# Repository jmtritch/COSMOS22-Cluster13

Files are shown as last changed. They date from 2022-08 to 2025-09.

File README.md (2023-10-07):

# UCSD COSMOS 2022 Cluster13 - H4O: Hacking for Oceans

This Cluster was inspired by the success of the [Scripps Institute of Oceanography and UCSD’s Hacking for the Oceans](http://h4oceans.ucsd.edu/) graduate and undergraduate level class.

During this inaugural year students applied engineering theory and industry-recognized best practices in the development of affordable instrumentation and robotic devices by innovating and adopting new technologies to monitor, generate and analyze data for our oceans at scale. Students worked in teams to:

* Develop a surface unmanned autonomous vehicle (UAV) including testing and documentation.
* Select and integrate low power and affordable instrumentation for the UAV using microcontrollers.
* Collect, visualize, model, and analyize water quality data, including temperature, total dissovled solids, and pH levels.

Students explored and applied principles of autonomous robots, microcontrollers, Python, and data visualization and analysis tools.

Working in 5 teams, students had to achieve their team objectives while ensuring that their work integrated seemlessly with the work of the other teams.  This required teams to identify goals, project timelines, and protocols for communication between devices and team inputs and outputs.

## Video Overview

COSMOS 2022 Cluster 13 (https://www.youtube.com/watch?v=VEP8hvSK_jM)

## Teams

1. Boat
   * Worked on converting a Traxxas high-speed RC Boat into an autonomous boat: integrated a flight controller, GPS, and a radio for communicating with an autopilot software on a base station computer, designed and printed enclosures for protecting the electronics from water damage, and modified the steering system to be more agile.
2. Buoy
   * Designed and constructed the buoy-based instrumentation for data collection. Two buoys were constructed.  The first buoy was designed to collect sea-surface data with the instrumentation submerged off the sides.  The second buoy was designed to lower and raise sumbersible instrumentation to collect vertical profiles of water quality data.
3. Data Acquisition
   * Ensured accurate data readings by calibrating and oversampling the sensor data.  Programmed the microcontroller to send the sensor data to the telemetry microcontroller.  Multiple microcontrollers were necessary becasuse the instrumentation in the second buoy was packeged in a submersible payload. Worked collaboratively with the telemetry team to develop the communication protocol (serial) and data format for communication.
4. Telemetry
   * Responsible for data communication between buoys and base station.  Programmed a buoy-based microcontroller to receive sensor data via Serial connection, combine the data with a timestamp and GPS coordinates, and transmit that data via long range radio (LoRa) to the base-station.  The base-station LoRa microcontroller recieves the data and transmits it to a linux-based server via Serial connection.
5. Data Storage and Analysis
   * Configured the server to receive the sensor data from the telemetry team's base-station microcontroller via serial connection.  Designed a normalized database in SQLite to store the data.  Developed a python script to receive the data via serial connection and populate the database.  Developed a Python-based databoard to visualize the data as it is received.  Utilized Python and Jupyter notebooks to visualize, model, and analyze the data.

## Data Flow

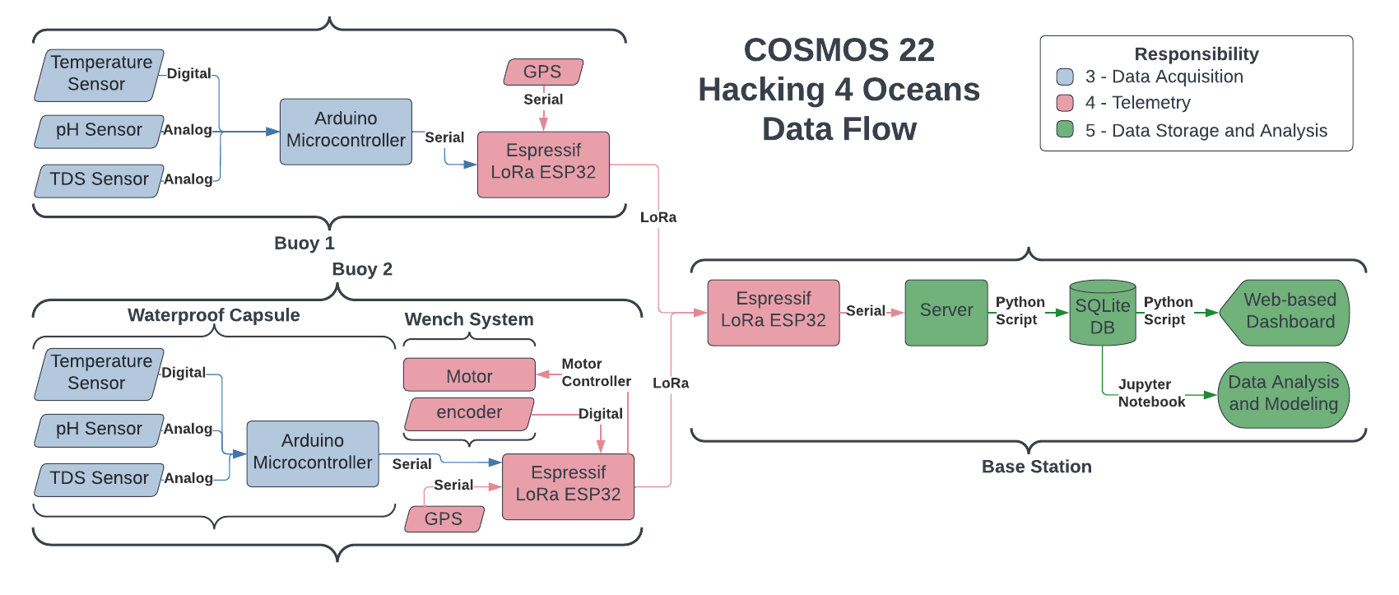
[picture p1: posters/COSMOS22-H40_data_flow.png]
Data Flow


## Team Posters

### 1 - Boat
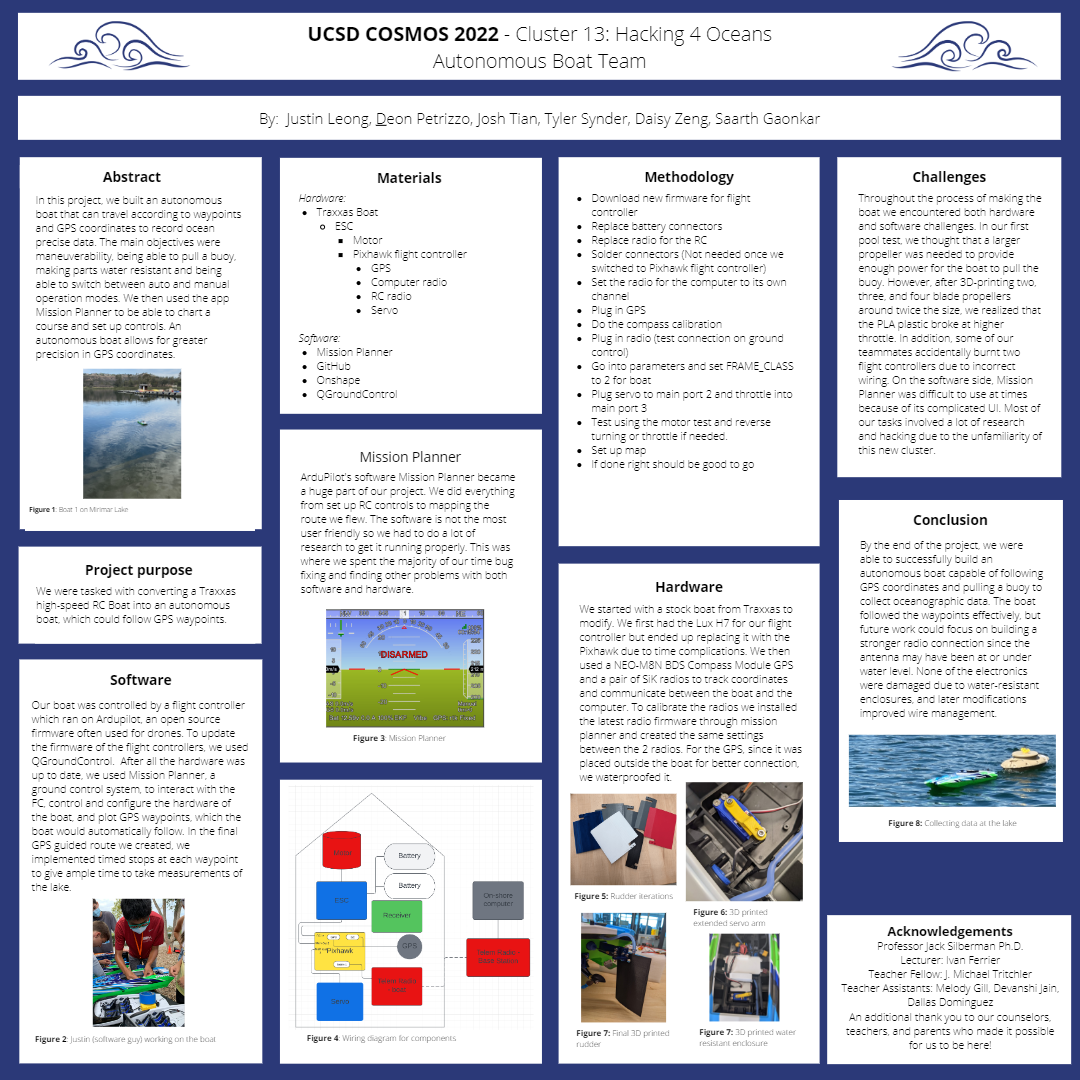
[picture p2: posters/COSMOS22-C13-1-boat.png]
Team 1 - Boat

### 2 - Buoy
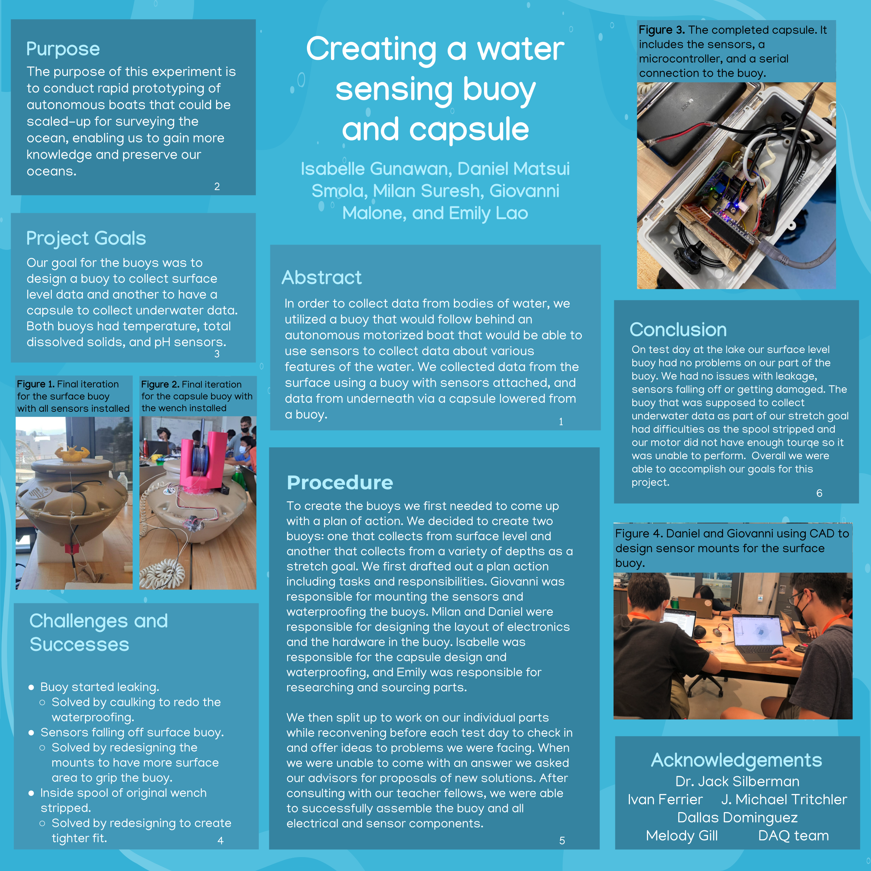
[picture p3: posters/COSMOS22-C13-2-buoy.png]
Team 2 - Buoy

### 3 - Data Acquisition
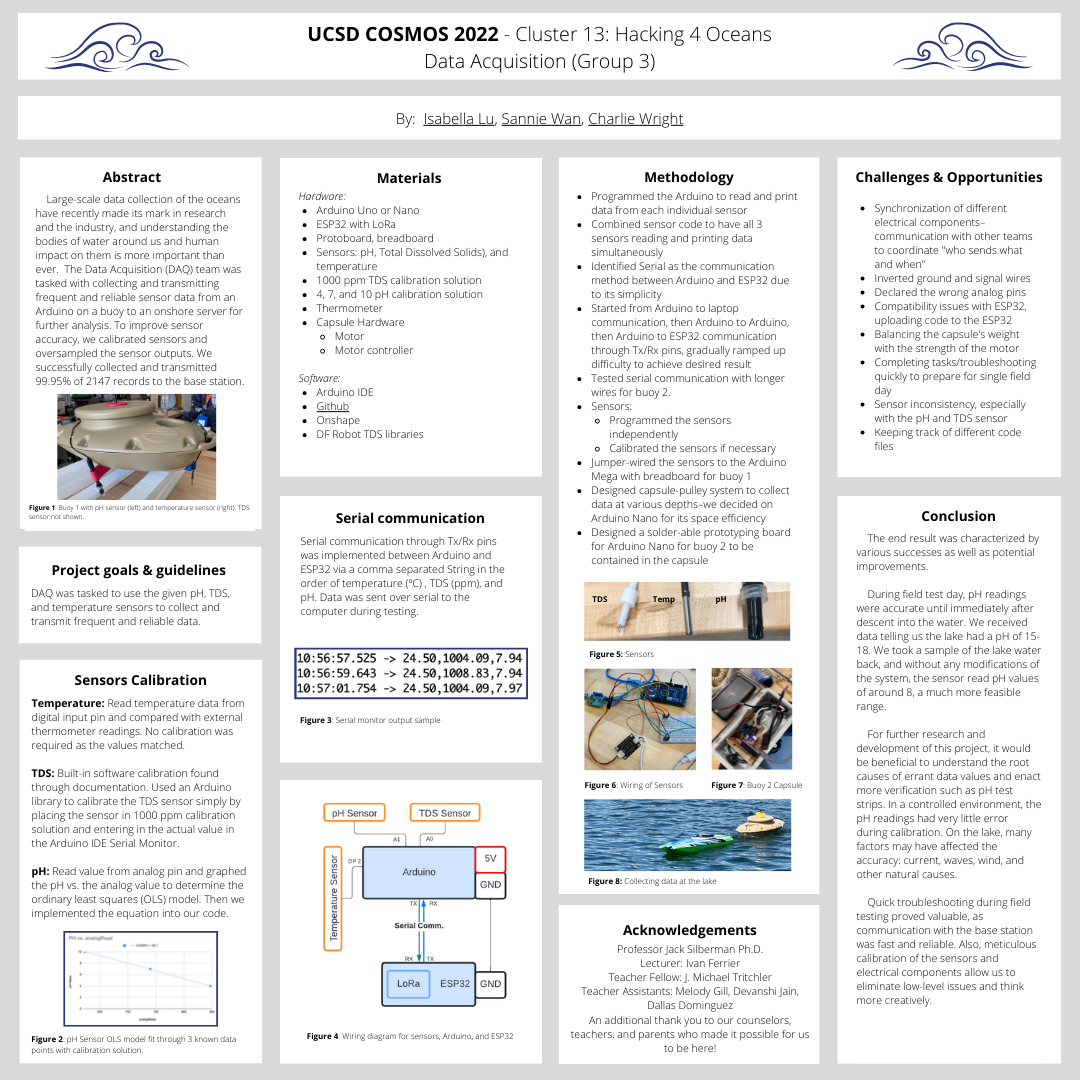
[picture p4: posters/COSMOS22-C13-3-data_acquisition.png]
Team 3 - Data Acquisition

### 4 - Telemetry
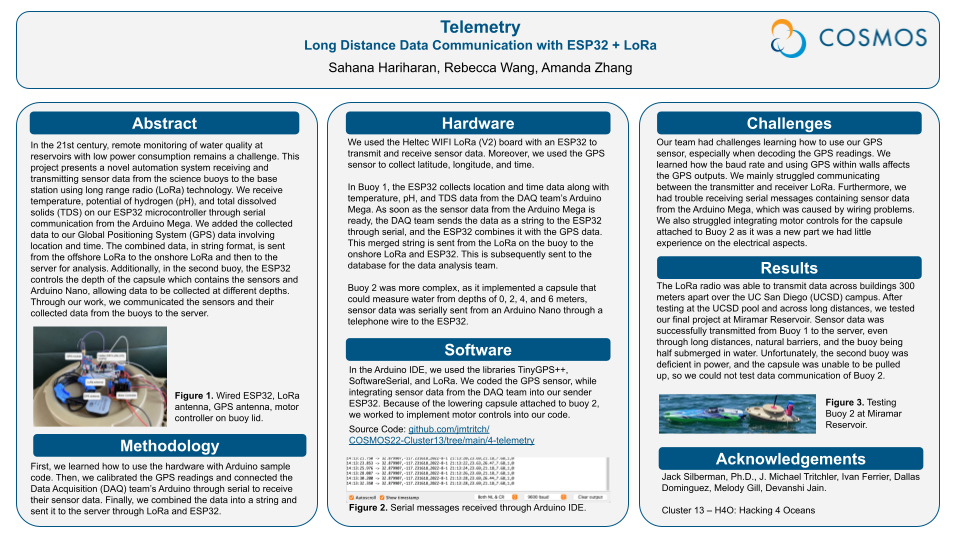
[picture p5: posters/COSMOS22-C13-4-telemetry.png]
Team 4 - Telemetry

### 5 - Data Storage and Analysis
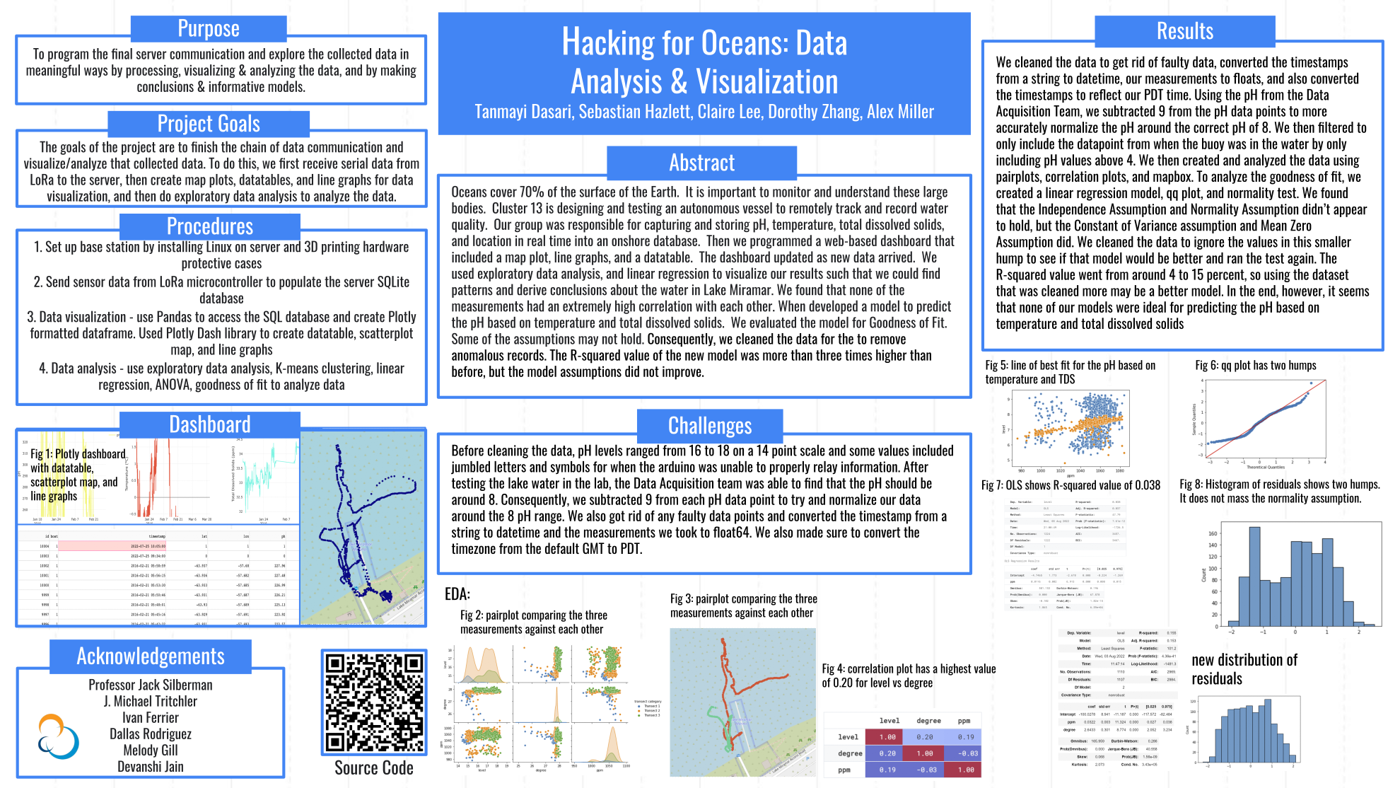
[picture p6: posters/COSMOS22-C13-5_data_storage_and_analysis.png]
Team 5 - Data Storage and Analysis


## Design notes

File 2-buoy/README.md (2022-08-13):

# Cluster 13 - Buoy Group
Team Members: Milan S, Daniel MS, Isabelle G, Giovanni M, Emily L



## Description
During the COSMOS 2022 Summer Program, we were in charge of creating a device to hold the water sensors and it's electronics. In order to do this, we utilized a buoy that would follow behind an autonomous motorized boat that would be able to use sensors to collect data about various features of the water. We collected data from the surface using a buoy with sensors attached, and data from underneath via a capsule lowered from the buoy. 

## Project Goals
Our goal for the buoys was to make one buoy a surface level sensor and the other have a capsule to get underwater data. Both buoys had temperature, solidity, and pH sensors. 

## Challenges
One of the challenges we encountered was the buoy that we were provided started leaking. We solved this by purchasing caulking and redoing the waterproofing. Another challenge was the sensor falling off which we solved by redesigning the mounts to have more surface area to grip the buoy with.

## Procedure
To create the buoys we first needed to come up with a plan of action. We decided to create two buoys one that scans surface level and another that can collect data from a variety of depths as a stretch goal. We first drafted out a plan of what we want to do and who would do what. Giovanni would be in charge of mounting the sensors and waterproofing the buoys, Milan and Daniel would be in charge of designing the layout of electronics and the hardware in the buoy, Isabelle would be in charge of the capsule design and waterproofing, and Emily would be in charge of sourcing parts. 

We then split up to work on our individual part while reconvening before each test day to check in and offer ideas to problems we were facing. When we were unable to come to an answer we asked our advisors for proposals of new solutions. After consulting our teacher helpers, we were able to successfully assemble the buoy and all it’s electrical and sensor parts. 

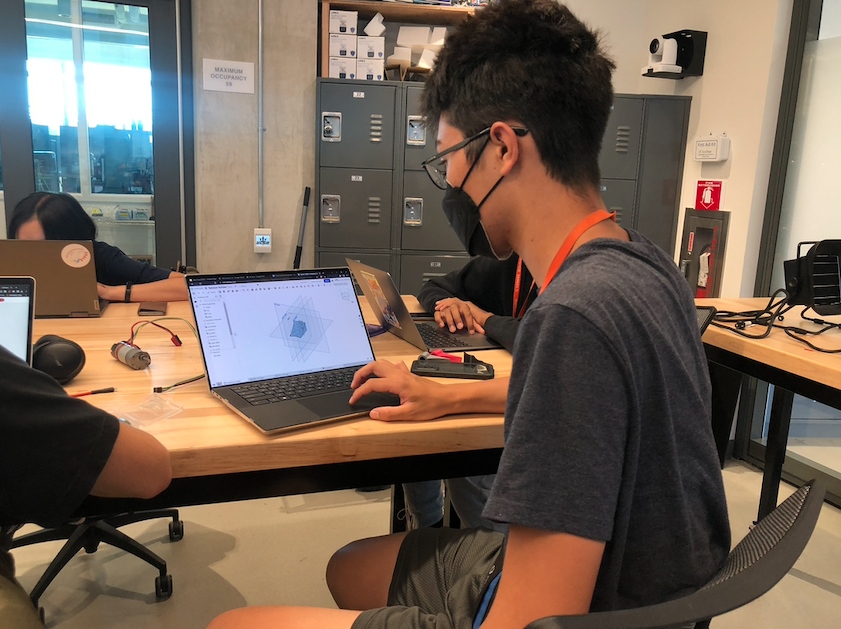
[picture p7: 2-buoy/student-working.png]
work


## Conclusion
After testing the buoys multiple times at the pool and once at the lake, we found that while our buoy was somewhat able to complete the tasks we had envisioned originally, it also had many flaws that hindered it. For one, we had many difficulties waterproofing it. However, we were able to create ingenious solutions using what we had, and were able to collect sufficient data to conduct scientific experiments.

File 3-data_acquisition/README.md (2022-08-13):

## UCSD COSMOS 2022
### cluster13 - DAQ
***
#### Team Members
Charlie Wright, Sannie Wan, Isabella Lu



***
#### Project and Purpose
Cluster 13 H4O plans to build an autonomous boat that'll tug a buoy along. The buoy will collect data (pH, temperature, tds) using a submersable capsule that'll send the data back to the database via Long Range Radio (LoRa).

Group 6 DAQ's role in this project is to assure accurate data readings and program the necessary hardware to send the capsule's data back to the buoy, in order for the buoy to be able to send the data to the database.

***
#### Tasks and Responsibilities
- Calibrating the sensors
- Wiring the sensors
- Reading data from the sensors
- Serial communication (ESP32 - Arduino)


***
#### Materials
Hardware:
- Arduino [UNO](https://store-usa.arduino.cc/products/arduino-uno-rev3), [MEGA](https://store.arduino.cc/products/arduino-mega-2560-rev3), or [NANO](https://store.arduino.cc/products/arduino-nano)
- [ESP32](https://heltec.org/project/wifi-lora-32/)
- Jumper wires, wires
- Protoboard, breadboard
- Solder
- Hall effect sensor (to pull capsule back up)
- Sensors: [pH](https://www.amazon.com/GAOHOU-PH0-14-Detect-Electrode-Arduino/dp/B0799BXMVJ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), [TDS](https://www.amazon.com/KEYESTUDIO-Quality-Monitoring-XH2-54-3Pin-Connector/dp/B08DGLY3J2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) (total dissolved solids), and [temperature](https://www.amazon.com/Gikfun-DS18B20-Waterproof-Digital-Temperature/dp/B08V93CTM2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)
- Calibration solutions: [pH](https://www.amazon.com/Atlas-Scientific-Electrode-Calibration-Solution/dp/B0063MVU5S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), [tds](https://www.amazon.com/HM-Digital-1000ppm-Calibration-Solution/dp/B001FD6WZ8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)
- [Thermometer](https://www.amazon.com/Yacumama-Instant-Thermometer-WATERPROOF-Grilling/dp/B087XBXFM6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) (temp sensor calibration)

Software:
- Arduino IDE
- Github
- Google Photos
- Discord
- Onshape


***
#### Github Navigation
- find older code files in the "old" folder, most of these are not being used
- for basic serial communication between two arduinos, check out the arduinomegaserial folder
- basic serial communication between esp 32 and arduino is in esp32-serial folder
- finalized code files are the following files


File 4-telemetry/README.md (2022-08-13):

# COSMOS22-Cluster13

## Poster Summary
Imgur

## Abstract
- Configured LoRa and worked with data acquisition (DAQ) and database teams
- Collected GPS data and combine with sensor data 
- Received data on server through onshore LoRa and ESP32 

## Methodology 
1. Sampling code to learn to use new hardware and software
2. Debugging software + electrical issues 
3. Collaborating with data acquisition and database teams to merge code into ESP 32

## Data Communication FLowchart
Data Communication Diagram

## Hardware
Imgur
Wired GPS, encoder, ESP32
Imgur
Final wiring on buoy
Imgur
LoRa antenna

## Software
Arduino Libraries: TinyGPS, SoftwareSerial, and LoRa.
Source Code: https://github.com/amndazhang/telemetry

Imgur
ESP32 receiver display
Imgur
Serial messages received

## Challenges
Imgur

## Results
- LoRa radio could send across very long distances
- Miramar Lake - sensor data was successfully transmitted from one buoy to the server
- Challenges with the 2nd buoy

Imgur
Data shown on web server!

## Acknowledgements
Thanks to COSMOS UCSD Cluster 13, Ivan Ferrier, J. Michael Tritchler, Dallas Dominguez, Melody Gill, Jack Silberman, and Devanshi Jain for all their hard work!

#### The Team: Amanda Zhang, Rebecca Wang, Sahana Hariharan

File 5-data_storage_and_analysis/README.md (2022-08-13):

# COSMOS22-Cluster13

## Team 5: Data Analysis
We analyze the data, program the server and communication, process the data, make conclusions & cool models.

### OUR TEAM
* Tanmayi Dasari - @tanmayi2 - rising junior at Cupertino High School
* Sebastian Hazl - @ZopesPrograms - rising junior at the Webb Schools of California
* Claire Lee - @clairecgl - rising senior at Canyon Crest Academy
* Alex Miller - @Genos160 - rising senior at Mountain View High School
* Dorothy Zhang - @8Dorothy8 - rising junior at Menlo School

### BRAINSTORMING/PLANNING
During the first week of our 4-week program, our team worked on getting familiar with the project, what changes we would be making to our RC boat, dividing up tasks, learning CAD, and understanding Arduino. Below is a Gantt chart of our last 3 weeks that we created to map out our work.

<p align="center">

</p>

Additonally, here is our initial brainstorming diagram displaying the flow of data towards the server from the boat/data buoy. This diagram is an overview of Groups 5, 6, and 7. The highlighted blue section on the right is what our team worked on and the formatting at the bottom is what our data looks like.

<p align="center">

</p>

### WEEK 2
During the second week, our team learned about database structure using SQLite and created a database to store sensor, GPS, and timestamp data. We decided on using serial with Telemetry Team to transfer the data. Sebastian started working on transferring the data from serial to the database using Python. Dorothy and Tanmayi decided on Plotly Dash as the library for the dashboard and planned out the layout of the dashboard. Claire and Alex started to learn Python to create models. Claire delved into exploratory data analysis and started learning about K-means clustering, linear regression, and goodness of fit for our data analysis. Meanwhile, Alex set up the server with the Linux OS.

### WEEK 3

We worked on OLS and ANOVA models for data analysis, as well as continuing work on the dashboard. We completed dashboard plot code and tested the live updates on dashboard. Finally, we CADed the radio-to-stand connector of LoRa and server, an esp32 protective box, and LoRa reciever case. On Friday, we went to the Miramar Lake for the final test of our roboboat. We got to see data send to our dashboard and update on refresh!

<p align="center">
  
  
</p>
<p align="center">
  
  
</p>

### RESULTS
We cleaned the Miramar data to get rid of faulty data, converted the timestamps from a string to datetime, our measurements to floats, and also converted the timestamps to reflect our PDT time. Before cleaning the data, pH levels ranged from 16 to 18 on a 14 point scale and some values included jumbled letters and symbols for when the arduino was unable to properly relay information. After testing the lake water in the lab, the Data Acquisition team was able to find that the pH should be around 8. Consequently, we subtracted 9 from each pH data point to try and normalize our data around the 8 pH range. We then filtered to only include the datapointsfrom when the buoy was in the water by only including pH values above 4. We then created and analyzed the data using pairplots, correlation plots, and mapbox. To analyze the goodness of fit, we created a linear regression model, qq plot, and normality test. We found that the Independence Assumption and Normality Assumption didn't hold, but the Constant of Variance assumption and Mean Zero Assumption did. We cleaned the data to ignore the values in this smaller hump of the pairplot to see if that model would be better and ran the test again. The R-squared value went from around 4 to 15 percent, so using the dataset that was cleaned more may be a better model. In the end, however, it seems that none of our models were ideal for predicting the pH based on temperature and total dissolved solids.

<p align="center">
  
  
</p>

### CAD FILES
[ESP32 Lora Box](https://cad.onshape.com/documents/56a8fb3fd00b3845ea2166cb/w/2508b748c3d5bb36ff4afc42/e/4aeaa9f6f6c22c6a869a5fb2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)

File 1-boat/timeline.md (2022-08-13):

# **Timeline**
A documentation of our project progression: our challenges, breakthroughs, engineering process, and lessons learned.

## **Installing ArduPilot and Mission Planner**

* After we unboxed the flight controllers (Lux HD H7), we flashed ArduPilot, an open-source autopilot system for RC vehicles, onto the board. Initially, the flight controllers were not detected by the computer, so we had to install virtual com ports and DFU drivers. After connecting the board to STM32cube, we wiped the device and successfully flashed the firmware. 
* Ardupilot is the firmware for the flight controller, and Mission Planner is a ground control system for controlling the vehicle remotely. This software proved to be a large hurdle for the group, since the maze-like UI, hundreds of customizable functions, and parameters hid the basic features required to run the boat. After extensive research on RC forums and several Youtube videos, we became familiar with the program and changed specific parameters to fit our boat. ArduPilot is meant for drones and land vehicles, so all the features of ardupilot are meant to fit these machines. Instead, we built what is called an “arduboat:” a boat with ardupilot firmware. This allows for automation and all the same features as a drone. After installing and connecting the board, we moved onto the auxiliary hardware of the boat.
* Check out the [tutorial](https://github.com/jmtritch/COSMOS22-Cluster13/blob/main/1-boat/ARDUBOAT_TUTORIAL.md) Justin made for setting up an "arduboat" and using Mission Planner to plot and run autonomous paths.

## **Electronics**

### **Lux HD H7: Pin diagrams**

* After setting up the flight controllers, we looked at the specific pinout diagrams for our board. These diagrams explained what each pin was used for which allowed us to connect the flight controller to each of the devices correctly.

### **Soldering**

* After a week of making unsecure connections with tape, Ivan taught us how to solder, which allowed us to solder pin headers to the flight controller and female headers to external components, so we could easily plug in components into the flight controller.

### **Sik radio connection**

* We used 2 Sik radios, with one of the radios connected to a laptop and another radio hooked up to the flight controller. The sik radios link up to each other and flash different colors to tell the user its connection status. For example, blinking green lights represent 2 radios searching for a connection, while solid green means they have established a connection with one another. Initially, the radios were not connecting, with one of the radios always turning red. However, we later discovered that the connection between the radios depended on their air speed, net ID, and firmware. In order to configure these settings, we paired the radios by changing the net ID, airspeed, and firmware to match in qgroundcontrol. We used only one pair of radios in our test, but using multiple pairs would require different net IDs to avoid interference.

### **GPS**

* Initially, wiring the GPS proved to be a challenge. Two of the GPS wires were black, with only one as ground. After opening the GPS, we found that the thicker black wire represented ground. Later, we wired the GPS to the board but made the mistake of connecting Rx to Rx and Tx to Tx rather than connecting respective receiving and transmitting wires together [[GPS internals](https://github.com/jmtritch/COSMOS22-Cluster13/tree/main/1-boat/boat-team-images/gps-internals.jpg)]. After solving this problem, the GPS functioned properly. While troubleshooting, we made a few unfortunate mistakes and burnt two GPSs.

### **Burning flight controllers**

* Instead of stepping down the voltage of one of our batteries to 7.4 volts before connecting it to the flight controller, one of our teammates accidentally plugged our flight controller directly into the 12.6 volt output of the lipo, instantly overloading the board.

### **Batteries**

* We did not want to use expensive Traxxas batteries, so we instead soldered 3 cell lipo batteries. We also utilized plug-in battery monitors to alarm us if the batteries died.

## **Manual three-channel RC control**

* We decided to use another RC controller (TGY-i6S) instead of the default Traxxas controller because we needed more channels in order to override autonomous control and switch to manual control. We first tested manual control by pairing the receiver, which uses PWM to control the servo and ESC, with the RC controller. This was a fairly straightforward process, but we had to ensure that the joysticks and switch on the controller were configured to the right channels [[pairing the radio](https://github.com/jmtritch/COSMOS22-Cluster13/tree/main/1-boat/boat-team-images/pairing-radio.jpg)]. We could manually test which channels corresponded to the servo and throttle by navigating to the menu and individually testing each motor. On a side note, we could only pair the default Traxxas controllers outside the classroom, likely due to interference.

## **3D-printed water resistant enclosures for electronics**

* For all of our electronics, we printed water-resistant enclosures [[electronics boxed](https://github.com/jmtritch/COSMOS22-Cluster13/tree/main/1-boat/boat-team-images/electronics-boxed.jpg)]:
    * For the radio and receiver, we printed cases with tight lids and holes for external wires to pass through. These holes were sealed with hot glue although we would have preferred to use silicon as a more professional solution.
    * For the flight controller, we designed and printed a watertight enclosure and a mount for the enclosure which interfaced with holes already present on the boat.
    * In the end these enclosures proved advantageous with no damaged electronics while testing the boat.
    * The enclosure for the flight controller, which we eventually modified to fit the Pixhawk instead of the Lux HD H7, went through a lot of [iterations](https://github.com/jmtritch/COSMOS22-Cluster13/tree/main/1-boat/boat-team-images/fc-enclosure-iterations.jpg).

## **First pool test!**

* After our first boat test in the pool, we decided to 3D-print larger propellers because it seemed like the boat did not have enough power to comfortably pull the load (buoy). We decided to design and print propellers around twice the size of the original propeller and made a few versions, each with a varied number of blades (two, three, and four) [[3dp propellers](https://github.com/jmtritch/COSMOS22-Cluster13/tree/main/1-boat/boat-team-images/3dp-propellers.jpg)]. However, because we used PLA, a fairly brittle plastic, and didn’t add reinforcements to our design, the propellers broke in the water when the throttle was pushed too far [[broken props](https://github.com/jmtritch/COSMOS22-Cluster13/tree/main/1-boat/boat-team-images/broken-propellers.jpg)]. We later realized that the propeller was not the problem at all; if the boat was just operated at a low speed, not displacing the water too much, it could easily pull the load.
* We also found that the turning provided by the included rudder was far too slow with a really large turning radius. We suspected that this was due to the small surface area of the included rudder. We also noticed that though the servo had 180 degrees of freedom, the rudder only had about 90 degrees of freedom. 
* With these observations in mind, we set out to design our own rudders and servo attachment to improve turning agility.

## **Second pool test!**

* In our second pool test, we tested our new steering system, which worked better than we expected, allowing us to make very tight turns and easily maneuver within the skinny pool lane we had access to. This was a result of two modifications to the original steering system:
    * Reorienting the servo to accommodate a longer [custom 3D printed lever arm](https://github.com/jmtritch/COSMOS22-Cluster13/tree/main/1-boat/boat-team-images/servo-mod.jpg) 
        * This increased the linear motion of the linkage that connects the servo to the rudder thereby increasing the rudder’s range of motion from ~90 degrees to almost 180 degrees
    * Designing a larger rudder which provided more surface area
        * This also helped reduce the turning radius; however, our first design was excessively large which both looked clumsy and produced unwanted drag even at our slow operating speeds, so we iterated on the design making smaller sizes when we got back to the classroom [[rudder iterations](https://github.com/jmtritch/COSMOS22-Cluster13/tree/main/1-boat/boat-team-images/rudder-iterations.jpg)].
        * Our rudder designs also have a hole for water to pass through to the cooling system within the boat.

## **Third pool test!**

* In our third pool test, we compared how the boat performed with different rudder sizes and found that the smaller rudder we tested didn’t sacrifice the turning radius and caused less drag than the larger rudder. We ultimately settled on the [medium sized rudder](https://github.com/jmtritch/COSMOS22-Cluster13/tree/main/1-boat/boat-team-images/rudder-mod.jpg) we designed
* NOTE: we also designed and printed an even smaller rudder but didn’t have time to test it. It likely would’ve performed comparably to the rudder we settled on, but we didn’t want to use it in our final trial because we didn’t test it and already knew the medium sized rudder performed well.

## **Pivot to PixHawk and autonomous navigation**

* After two weeks and four days of struggling with the Lux HD H7 flight controller, Jack gave us two Pixhawk 2.4.8s. This specific type of flight controller is loved by hobbyists for its functionality, robustness, and ease of use. We quickly researched the basics of the device and started anew. After a day and a half, we managed to make more progress with it than we had with the Lux HD H7. 
* One of the 2 Pixhawks broke in an accident where power was plugged into the wrong spot, causing the board to short.
* To simulate autonomous navigation with the boat without having to go in the water, we used Mission Planner to map points near the lab and run the autonomous mission while walking the boat around. This allowed us to see how the throttle and steering reacted as we moved it off-track. Through our testing, we noticed that the rudder was not moving and suspected that the channels were incorrectly configured. We were further convinced when we noticed that the throttle motor appeared to be modulating its speed in an attempt to steer. After experimenting with channel and motor configurations in Mission Planner, we realized that the PixHawk was wired incorrectly, and we changed the throttle from main out 1 to main out 2 and the servo from main out 8 to main out 3, which solved the problem. 

## **Lake day!**

* In the first test, we created a simple autonomous path, but when we ran it, the boat acted sporadically, going in circles, and we suspected that it was because of the rudder, so we inverted the servo rotation direction in Mission Planner and the autonomous navigation started working well. We then mapped a 27 waypoint grid-patterned path for the final mission, so the boat could stop 27 times to collect data from the lake and cover more area. 
* After adding the buoy though, the boat was not able to maintain its heading and started straying away from its path. Unfortunately, we ran out of time before we could get a chance to troubleshoot the issue, but we had our suspicions as to why it didn’t work:
    * The propeller possibly wasn’t generating enough thrust to pull the additional load (buoy)
    * The Sik radio which communicated with Mission Planner to get navigation instructions had the same frequency as the LoRa radio on the buoy and they may have been interfering with one another
    * For manual control: the radio receiver’s antennas were mounted very near water level and may have even been beneath water level in the boat, and since the radio communication only works in line of sight, there may have been complete loss of communication with the water blocking the signal

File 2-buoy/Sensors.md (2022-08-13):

For our sensors, we used a pH probe sensor, a temperature sensor, and a total-dissolved-solids (TDS) sensor

ph sensor temp sensor tds sensor

To mount our sensors we decided to create a 3D printed part that can hold the sensors that we could then use hot glue or epoxy to affix it to the side of the buoy. 
We needed to create three diferent cad models so we can mount ech of our sensors. 
The first CAD design was created to hold the [Tempature sensor]([https://pages.github.com/](https://cad.onshape.com/documents/50829009a772264103478846/w/c708d828623270150ef75e4e/e/50d666d81c3724e23ea0e39a)). 
It worked by having a curved side that matched the curvatiure of the buoy and a lego hand on the oposite side that would hold the wire. 
It would then be glued in to ensure no further movement. 

Then next design was the [TDS sensor holder]([https://cad.onshape.com/documents/0d5282bba14a224c1724f533/w/94f34ff72025ca8cc00cb65f/e/ccd35523a7df853023de6571))
We designed it so we can slide the TDS sensor into it before glueing the curved edge to the side of the buoy.
We initial planned to only have it hold the sensor but while testing we realised that the TDs sensor probe was being damaged during testing so we designed a attachment that covers the pins so they would not be damaged.

The final

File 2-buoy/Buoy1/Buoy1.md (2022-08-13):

# Buoy #1:
## Objectives:
* Collect data via sensors that would be attached to the exterior of the buoy
* Communicate with base station in order to send data back to be analyzed

## Project Timeline

### 7/18
We created the first iteration of the CAD models to hold the sensors.[PH sensor](https://cad.onshape.com/documents/ea41564105b61a12bdf0fd28/w/d3fdfa1f7d79284eb63dc095/e/69df08fe40578d68010a607e), [TDS sensor holder](https://cad.onshape.com/documents/0d5282bba14a224c1724f533/w/94f34ff72025ca8cc00cb65f/e/ccd35523a7df853023de6571) and the [Tempature sensor](https://cad.onshape.com/documents/50829009a772264103478846/w/c708d828623270150ef75e4e/e/50d666d81c3724e23ea0e39a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)

### 7/19
We finished printing out the sensor mounts and temprorily attached them to the buoy using hot glue.

### 7/20 
We took the buoy out to the pool to test how everything was working. We discovered that the TDS sensor needed to be more protected so we redesigned the cad model to have part of it extend underneath to protect the pins. 

### 7/21
We test fit the TDS sensor enclosure which worked so we temporarily attached it with hot glue.

### 7/22 
No changes to this buoy.(Brought buoy down to the pool to help boat team)

### 7/26
We designed and printed out a wire holder that when combined with hot glue makes how we run cables out of the buoy watertight.[TDS and PH wire holder](https://cad.onshape.com/documents/e784ea0fa94fbc70d4efa87f/w/58f1957ea31cdb04b8e44ff0/e/aa3c104410f8dd82f052ff10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) [Temperature wire holder](https://cad.onshape.com/documents/c1e1077623cafe5e9a5d7832/w/577200b50c6ec7e4d29fced9/e/af7030dff21ce8a0d2977259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). We also attached the sensors using epoxy so they would not fall off.

###7/27
The buoy flooded and we had to try to salvage the electronics. The buoy was also dropped, breaking the TDS sensor and the mounting of the PH sensor. We found out that the temperature sensor works properly but we need to replace the PH sensor due to water damage. We also had to replace the TDS sensor due to the pins being bent. Due to some of the sensors falling off of the buoy we redesigned the models to cover more surface area to create a better attachment point. We also had to reprint the sensor wire holders as we had to rerun the wires20220801_105324 (1)

###7/28
Finished rewiring the Buoy after finishing damage repairs

###7/29
The surface buoy had no problems.

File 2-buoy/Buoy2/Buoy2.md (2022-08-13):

## Buoy 2 
### Objectives:
Drop capsule into water using winch system to accurately measure pH, temperature, and total dissolved solids/salinity under the water’s surface
Communicate and distribute data to base station consistently

### Procedure

#### Winch System

We used a DC motor attached to a spool to unwind and wind fishing line, precisely moving the capsule above and below the water’s surface.

We used a rotary encoder in order to document the amount of rotations to figure out the depth of the capsule (each rotation accounting for 20cm of line). 

dfghjk

The body of the second buoy was also a CreekKooler cooler.

#### Communication

Arduino collects data in capsule (pH, temperature, TDS)-> Serial Communication with Capsule through telephone wire -> esp32 sends signal to base station through LoRa antenna



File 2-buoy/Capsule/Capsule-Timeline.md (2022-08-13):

## Timeline
| Date | Work done |
|---|---|
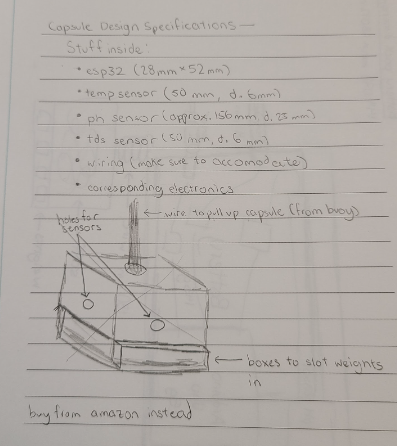
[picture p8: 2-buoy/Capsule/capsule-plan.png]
capsule sketch
| 7/19 | First design for capsule: <br />  |
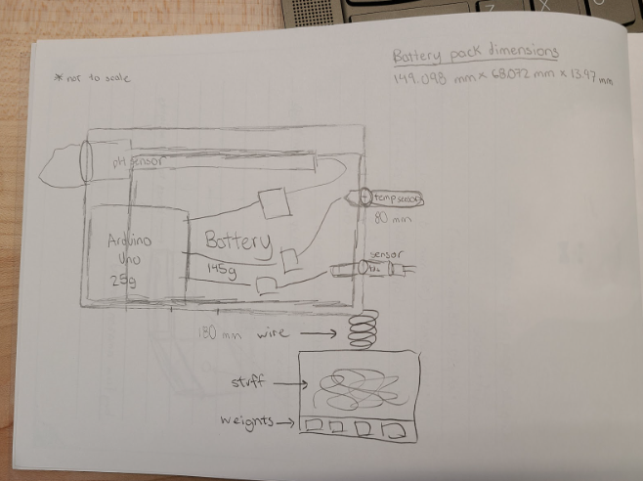
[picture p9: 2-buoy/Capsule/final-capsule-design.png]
final design
| 7/25 | Refined design of capsule layout: <br />  <br /> For the next design of the capsule, we decided to put weights on the bottom of the capsule, and all the necessary electronics on top. A platform would separate the electronics from the weights, and we would print securements and use velcro in order to easily remove and replace the electronics inside. To allow the sensors to extrude from the capsule without leakage, we would use a combination of cable grommets and epoxy. |
| 7/28 | [Capsule CAD](https://cad.onshape.com/documents/9a7321111b4570997014b95b/w/4ca52f9e492d14f44d9d2d3c/e/9bbe53ddc6703be7f722da70 "Capsule CAD") <br /> We received the new calibrated sensors from the data acquisition group. We then printed our newly designed sensor holders that maximized contact with the buoy. We then attached it to the buoy using epoxy to create a strong bond to the buoy that would not fail. <br /> Replaced rotary encoders with hall effect sensors. <br /> Coded up all the hardware. <br /> Wired together all the components of the capsule buoy. |

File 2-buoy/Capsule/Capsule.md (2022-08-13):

## Capsule

### Objectives:
* Create a capsule that can be easily lowered beneath the water
* Capsule has the capacity to collect data via sensors
* Capsule can send data back to buoy via serial communication

### Procedure:
For the body of the capsule, we used the Zulkit Junction Box, which was watertight and could thus protect the electronics inside. 

Inside of the capsule, we used an Arduino nano to control the sensors and a battery pack to power the Arduino. 
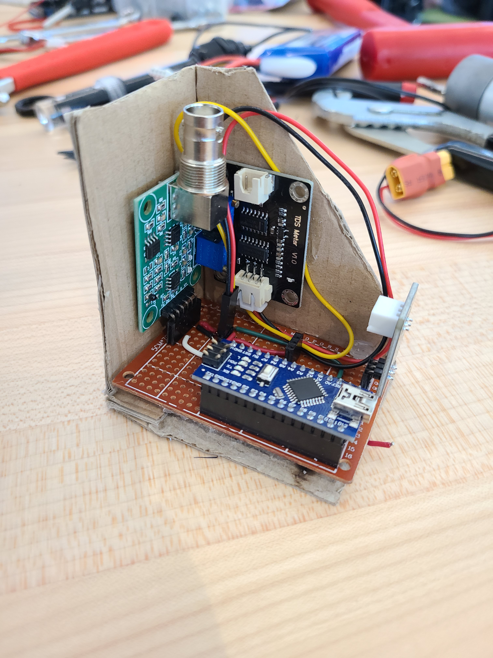
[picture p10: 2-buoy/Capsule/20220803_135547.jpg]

In order to allow the sensors to protrude from the capsule while also preventing water leakage, the sensors are threaded through cable grommets and secured in place using epoxy.

A telephone wire is used to establish serial communication between the microcontroller in the buoy and the arduino nano inside the capsule. 

To reel the capsule back up and lower it into the water, a strong fishing line is wrapped around the spool and tied to the capsule. 

Finally, weights are tied to the exterior of the capsule to make it heavy enough to sink in the water. 


### Final Product:




We successfully created a watertight capsule that was capable of sinking below the surface of the water to collect data. However, the external weights added too much weight to the capsule, causing some difficulties when reeling it back up. Additionally, there were some problems when communicating the data attained from the capsule sensors to the base station. To avoid these issues, the weights should be inside the capsule, and the telephone wire should be shortened to avoid data loss.

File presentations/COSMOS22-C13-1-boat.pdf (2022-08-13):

# Boat Team

Ty, Josh, Deon, Justin, Saarth, and Daisy

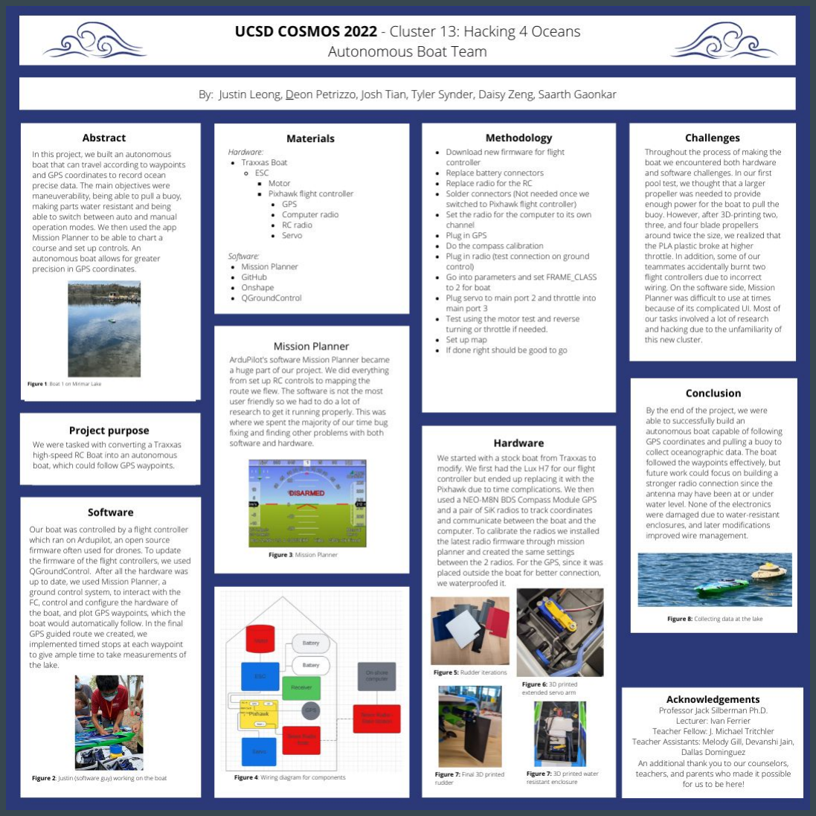
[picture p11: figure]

## Goals

- RC Boat => Autonomous Boat
- Maneuverability
- Pulling a load
- Water resistance
- Fail safe mechanism

## Software

- Ardupilot (firmware on flight controller)
- Mission Planner (ground control software)
- Configure hardware
- Plot and run GPS routes
- Add specific waypoint events

## Hardware: Electronics

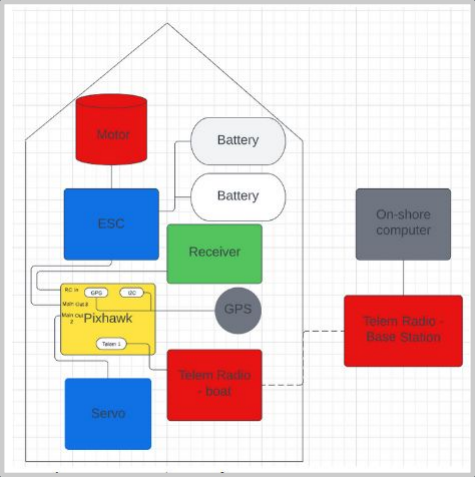
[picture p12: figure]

## Hardware: Custom 3D printed parts

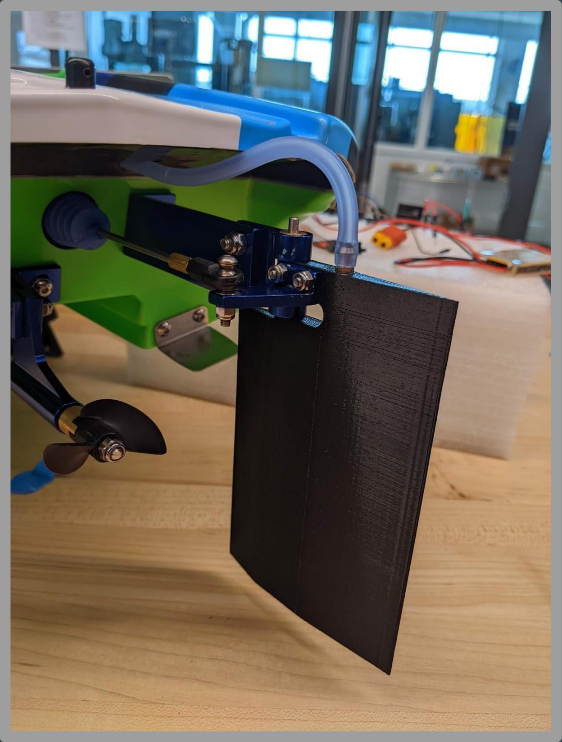
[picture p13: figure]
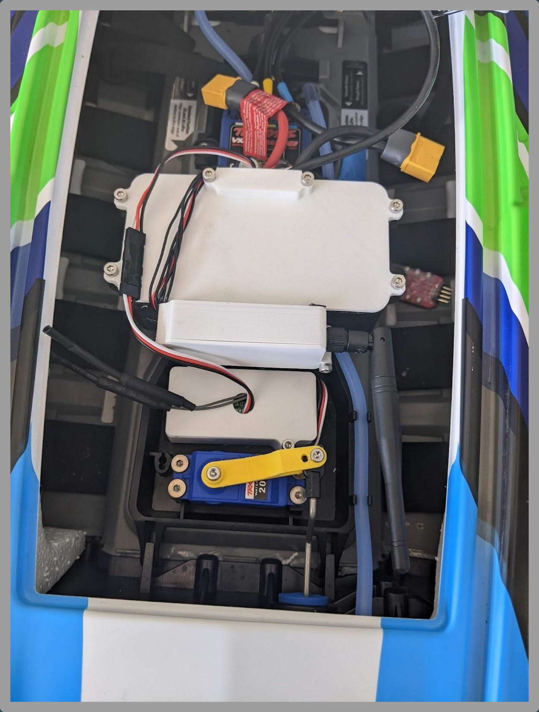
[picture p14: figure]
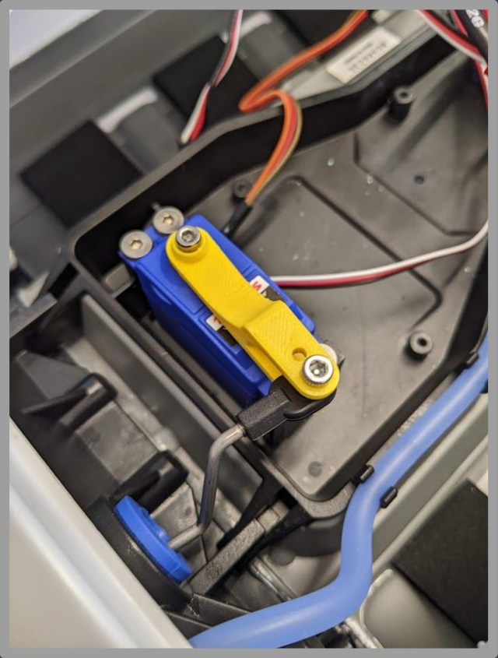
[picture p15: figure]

Improved steering system | Water resistant enclosures for the electronics

## Hardware: Iterations

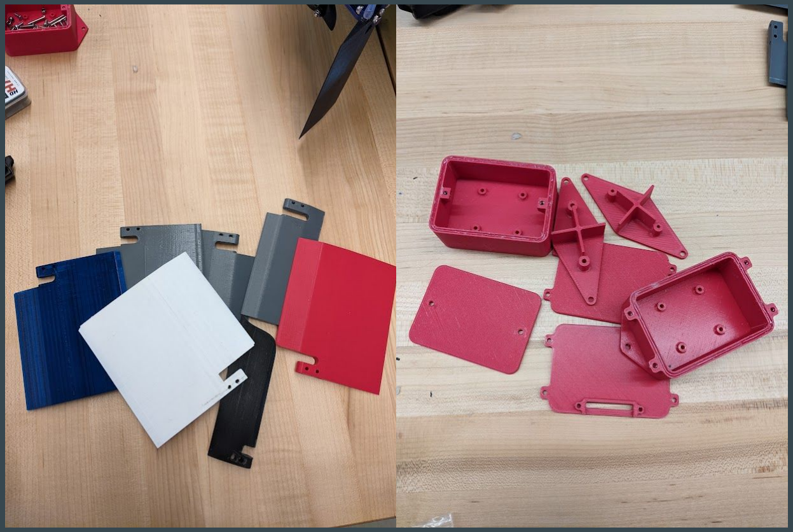
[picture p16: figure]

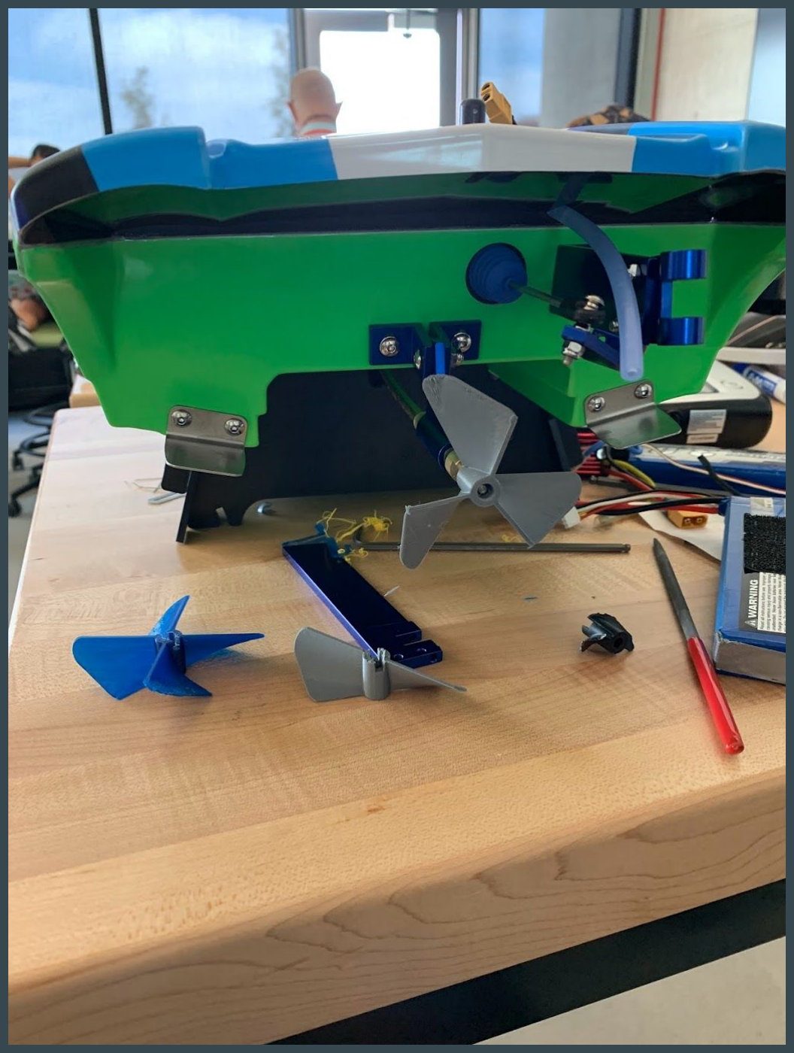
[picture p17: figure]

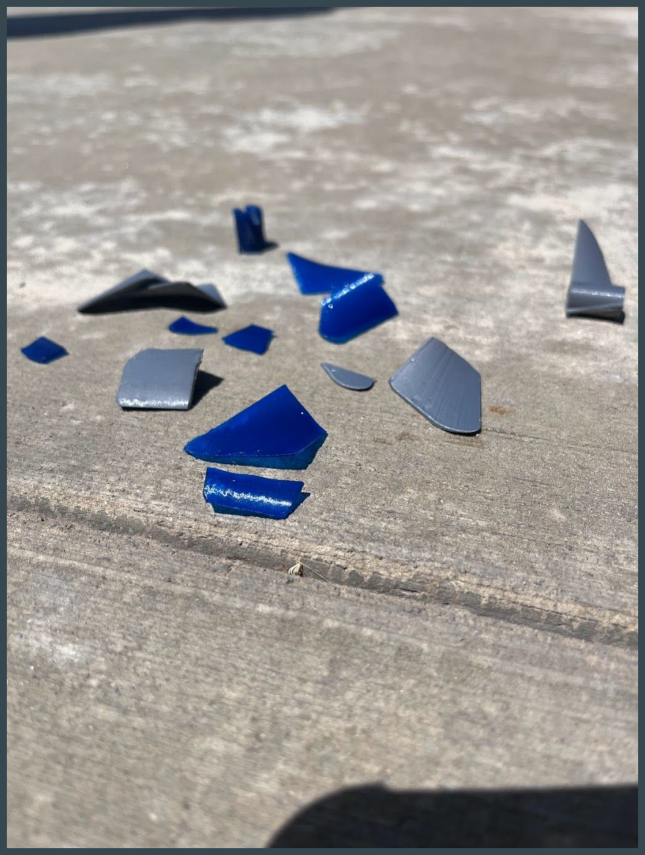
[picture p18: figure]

## Challenges

Hardware:
- Wiring GPS
- Frying boards
Software:
- Mission Planner => complicated UI
- Pairing Sik radios

## Conclusion

Success:
- Boat followed GPS waypoints
- No water damage
- Agile steering
Future Improvements:
- Stronger radio connection

## Acknowledgements

Professor: Jack Silberman Ph.D.
Lecturer: Ivan Ferrier
Teacher Fellow: J. Michael Tritchler
Teacher Assistants: Melody Gill, Devanshi Jain, Dallas Dominguez
An additional thank you to our counselors, teachers, and parents who made it possible for us to be here!

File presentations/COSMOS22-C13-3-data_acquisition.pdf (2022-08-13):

# UCSD COSMOS 2022

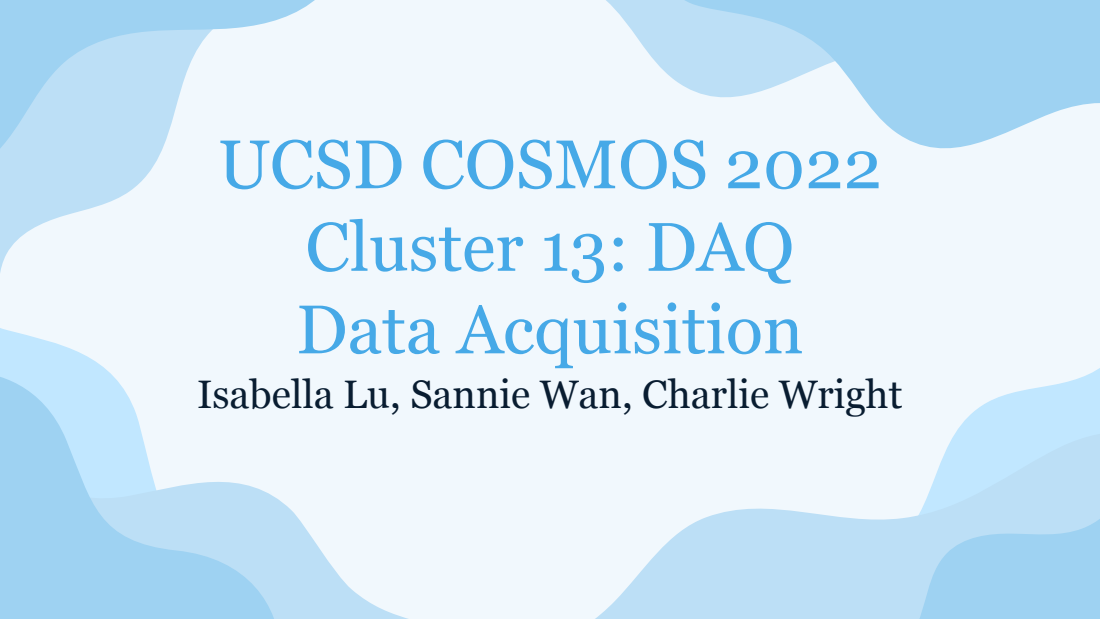
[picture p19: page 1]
Cluster 13: DAQ Data Acquisition

Isabella Lu, Sannie Wan, Charlie Wright

# Meet the Team

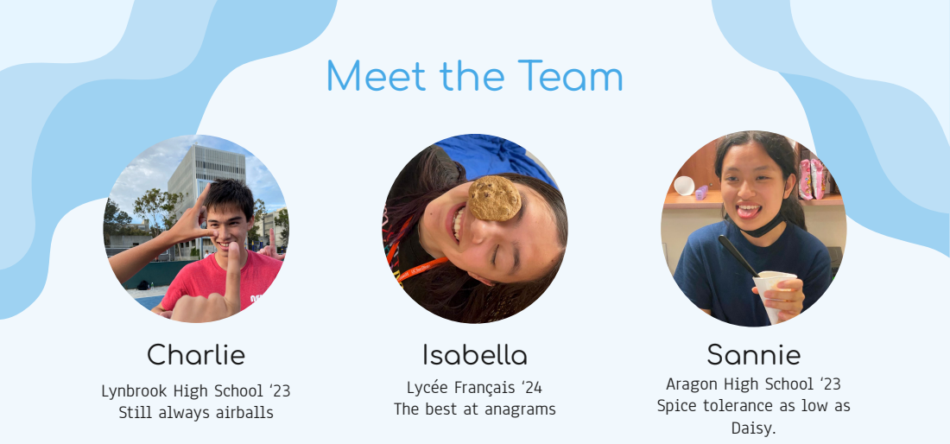
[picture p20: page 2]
Daisy.

Charlie
Lynbrook High School ‘23
Still always airballs

Isabella
Lycée Français ‘24
The best at anagrams

Sannie
Aragon High School ‘23
Spice tolerance as low as

# Background

There has recently been many contributions to big ocean data. In order to understand the environment around us through robotics, sensors were placed on a buoy, which was towed by a boat. This was driven around Miramar Reservoir.

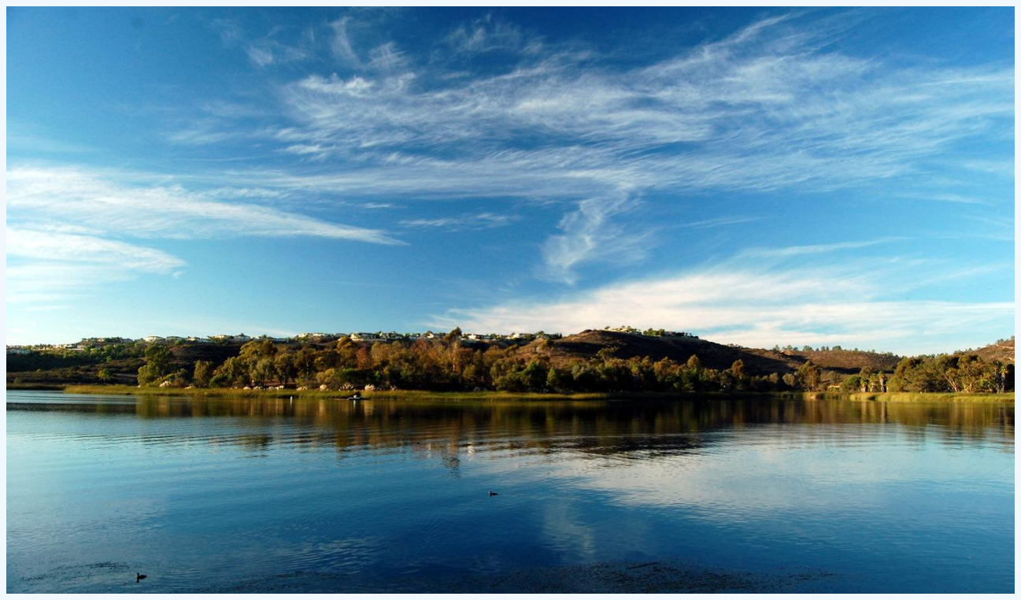
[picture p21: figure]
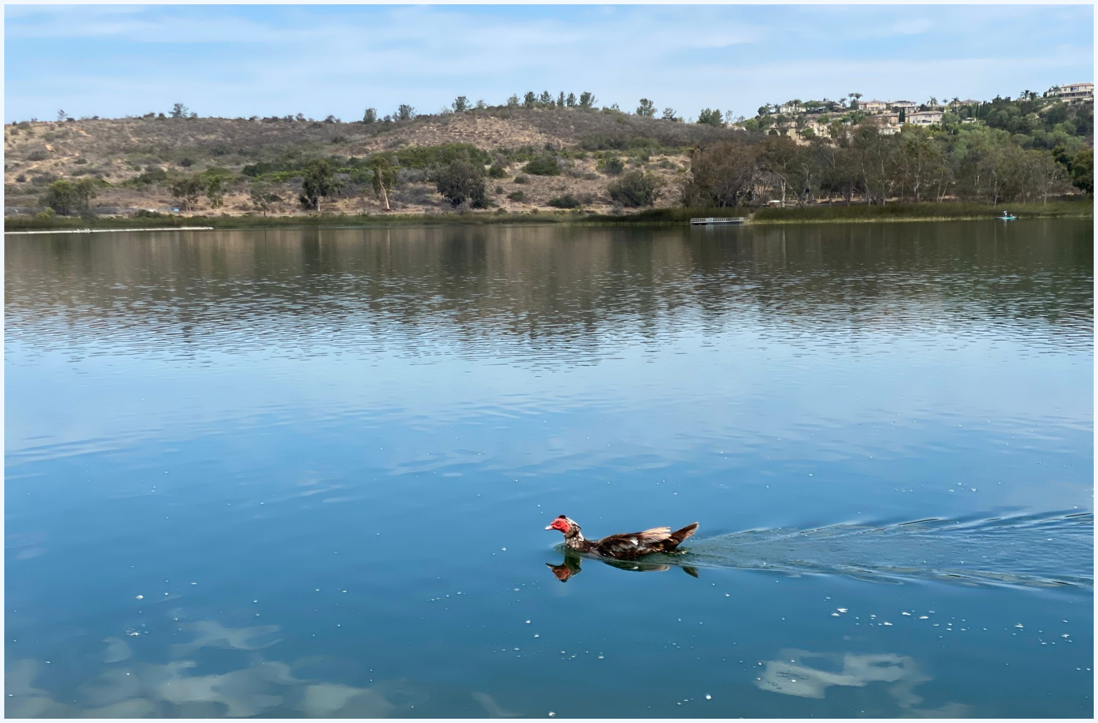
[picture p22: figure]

# Project Scope

Tasks:
- Use pH, TDS, and temperature sensors
- Collect and transmit frequent and reliable data.
- Wire up the sensors in the buoy

We communicated our data through serial communication from an arduino to ESP32.

Goal: collect pH, total dissolved solids (TDS), and temperature data from Miramar Lake, and send it back to an onshore server for further analysis.

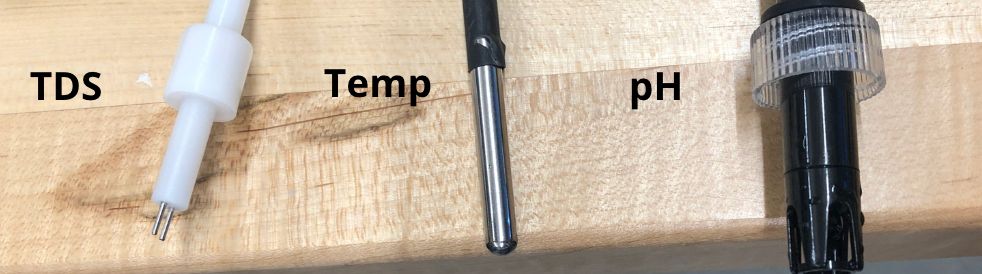
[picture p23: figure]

# Wiring diagram

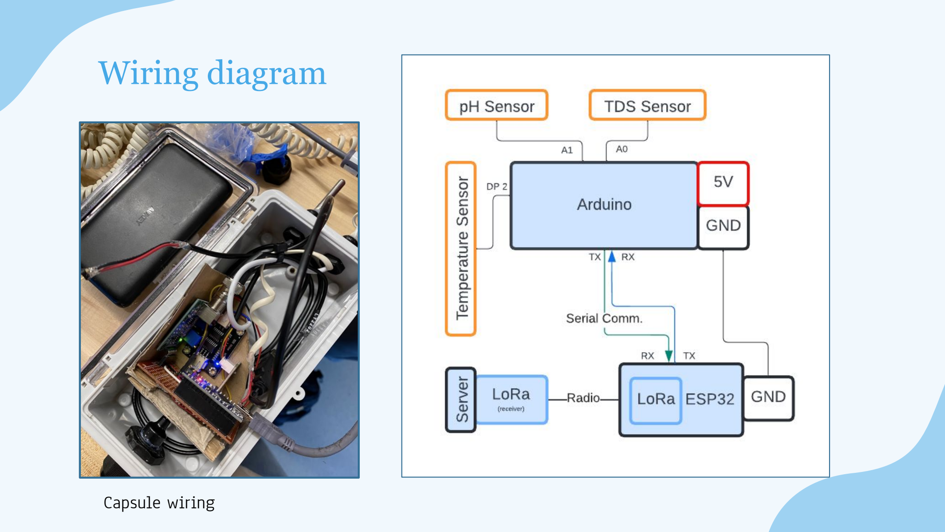
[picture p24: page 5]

## Capsule wiring

# Materials

Hardware:
- Arduino Uno and Nano
- ESP32 with LoRa
- Protoboard, breadboard
- Sensors: pH, Total
Dissolved Solids), and
temperature
- 1000 ppm TDS
calibration solution
- 4, 7, and 10 pH
calibration solution
- Thermometer
- Capsule
Hardware
- Motor
- Motor
controller

Software:
- Arduino IDE
- Github
- Onshape

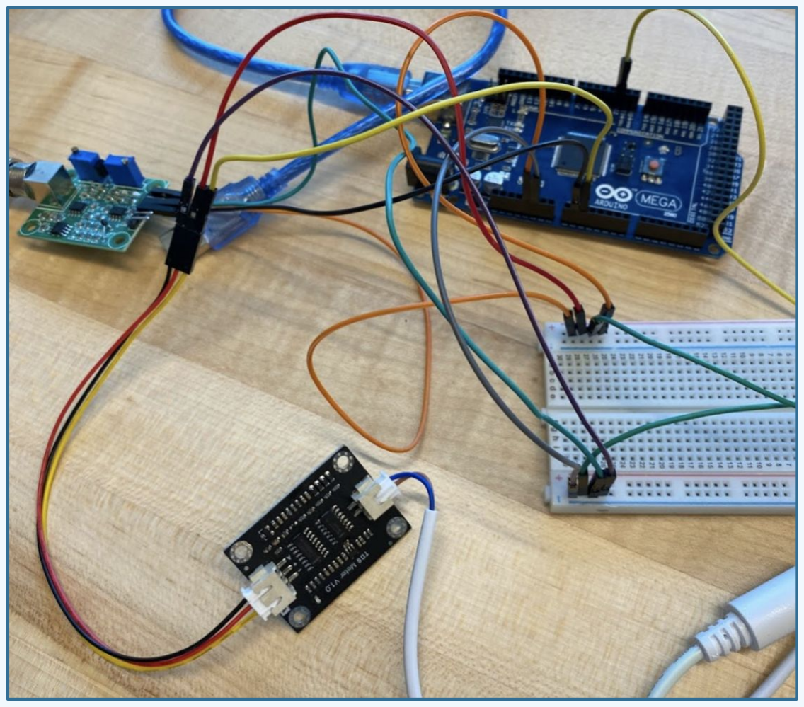
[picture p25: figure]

## Prototyping with breadboard and sensors

# Reliable Data Method

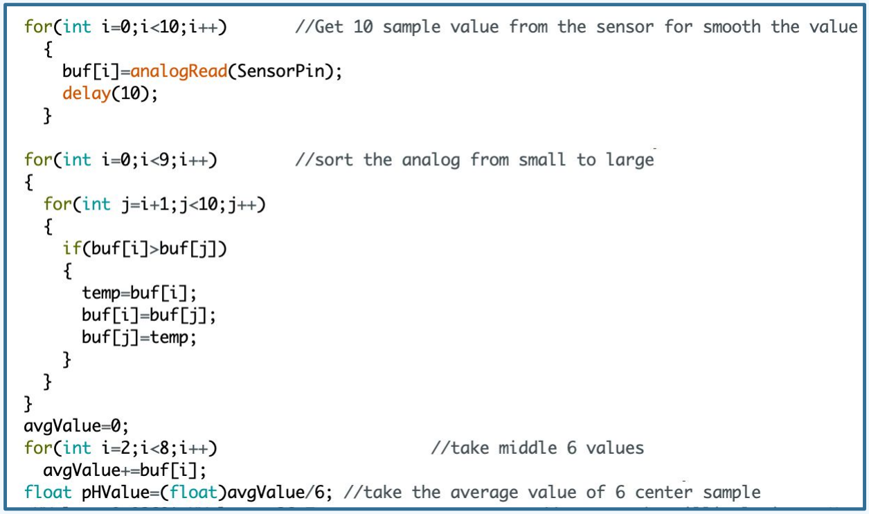
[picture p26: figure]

When taking the measurement of pH, we used:
- Oversampling (takes 10 values per function call)
- Averaging the six median values

pH oversampling →

# Sensors Calibration

We took three known data points for pH, plotted

them in a scatter chart in Google Sheets and used

the trendline tool to find the equation relating the

analog value to the actual pH value.

Then, we plugged in that equation into our

Arduino code.

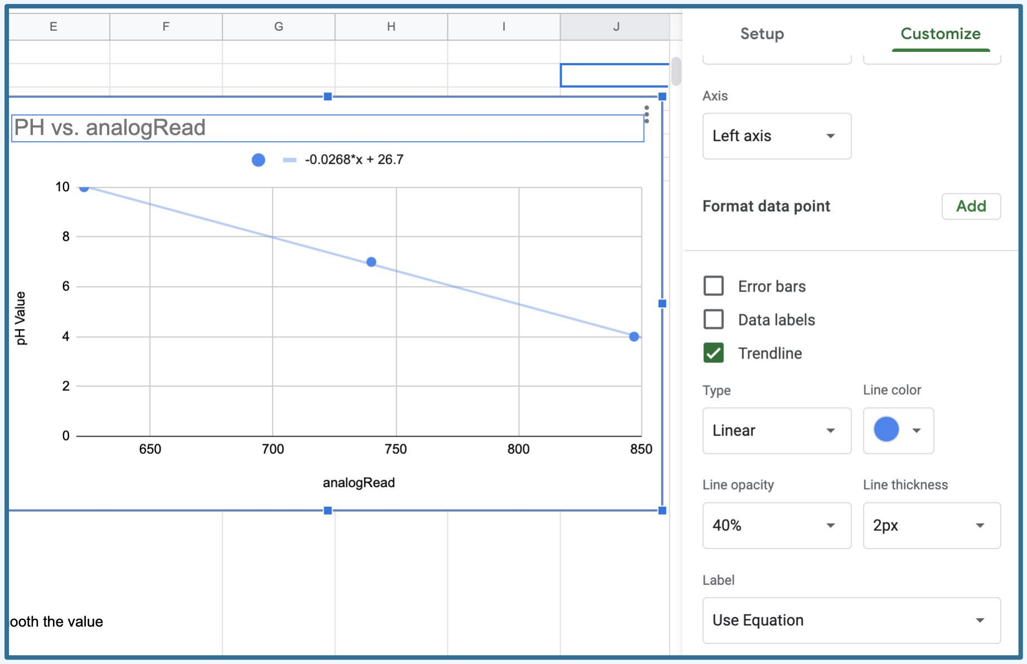
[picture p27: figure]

## Line of best fit on Google Sheets

# Challenges

- Synchronization of different electrical

components–communication with other teams to

coordinate "who sends what and when"

- Uploading code to the ESP32
- Flooding in the buoy
- Had to re-calibrate and test all sensors as

well as replace some

- Sensor inconsistency, especially with the pH and

TDS sensor

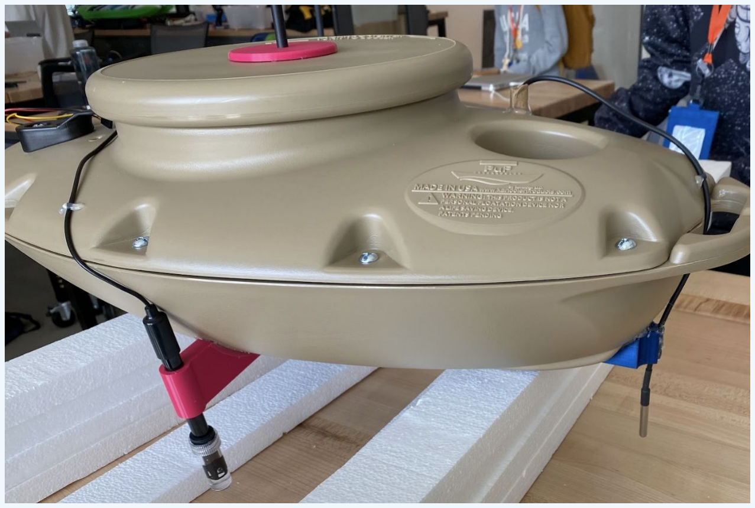
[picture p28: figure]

Buoy 1 with pH sensor (left) and temperature sensor (right). TDS sensor not shown.

# Field testing Results

- In a controlled environment, the sensor readings had very high accuracy
- Immediately after dropping in the lake, pH was inaccurate: 15-18
- Realistic pH: 7-8
- TDS might be too high: ~1000 ppm
- Realistic TDS: 50-300
- 2136 data points around the lake were collected
- Data was gibberish initially during testing due to a wiring malfunction, troubleshooted at the lake

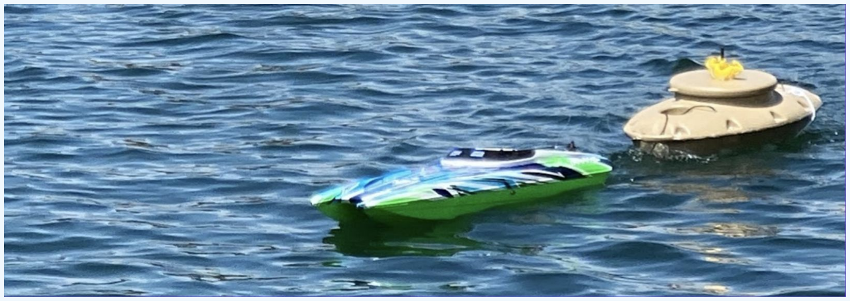
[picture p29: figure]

# Opportunities for further research

- Understand the root causes of wrong data values
- Possible reasons: wind, not fully submerged, current, temperature
- We tested fast-flowing sample lake water with pH sensor. The pH didn’t change significantly. According to our observations, current did not affect pH.
- Temperature of the lake was not in the extremes
- More verification such as pH test strips
- More time for field testing
- Testing sensors deeper in the lake

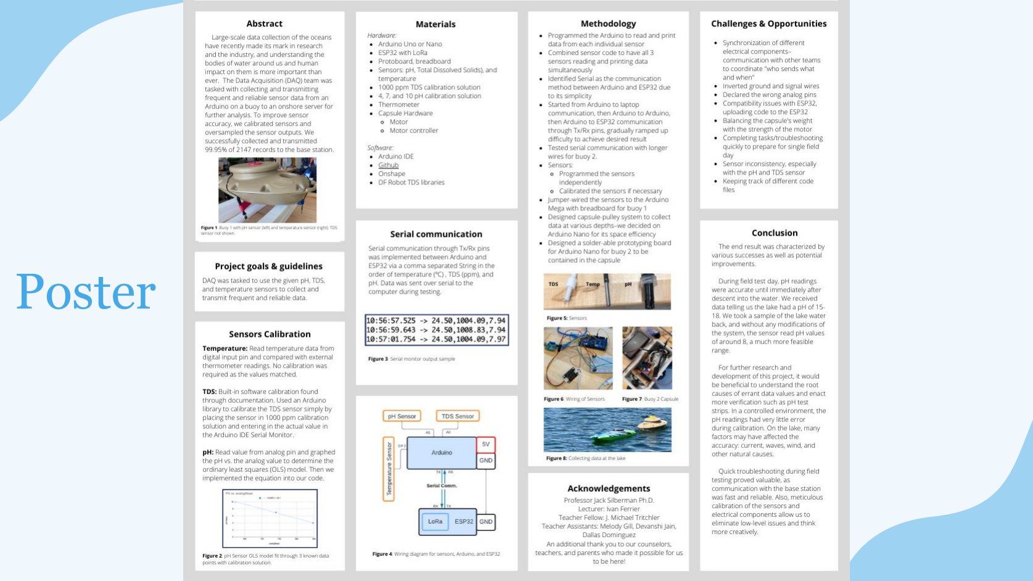
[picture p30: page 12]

# Poster

Thank you!

A special thank you to Professor Jack Silberman Ph.D., Lecturer Ivan
Ferrier, Teacher Fellow J. Michael Tritchler, and TA’s Dallas

Dominguez, Melody Gill, Devanshi Jain

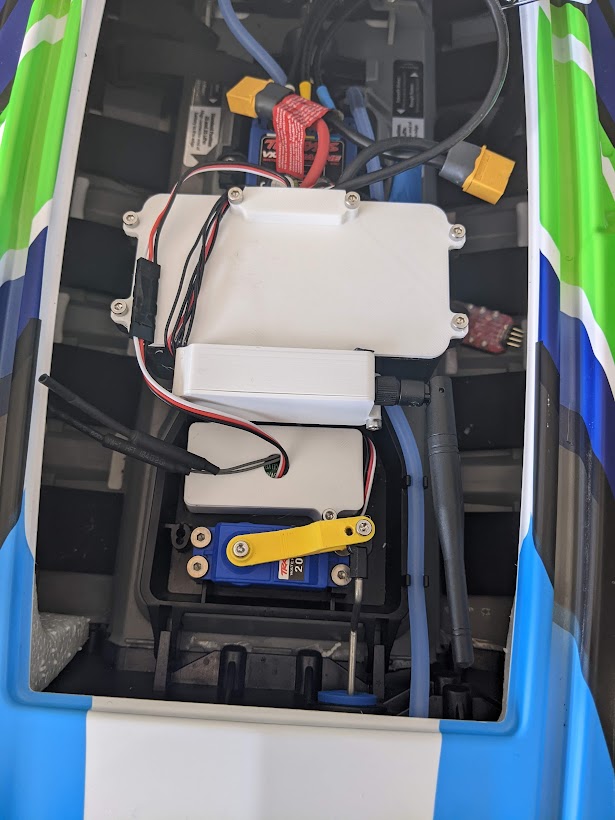
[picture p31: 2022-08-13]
1-boat/boat-team-images/electronics-boxed.jpg

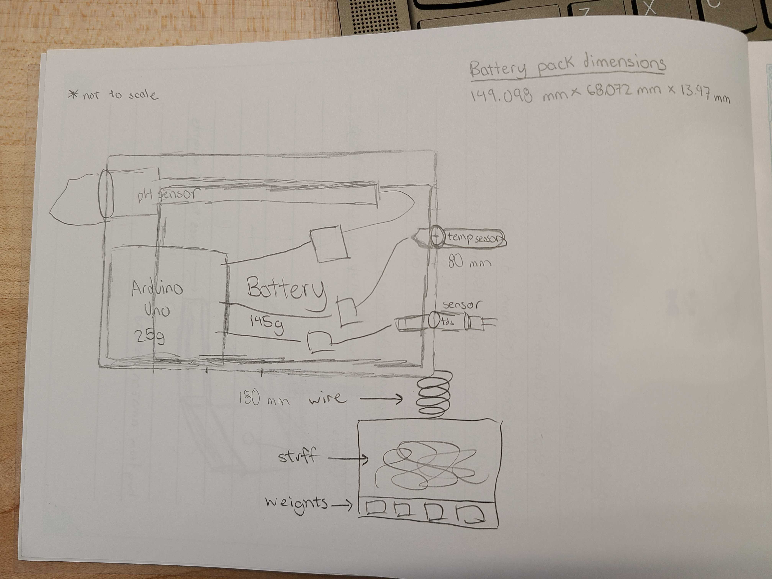
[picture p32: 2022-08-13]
2-buoy/Capsule/capsule_design_v2.jpg

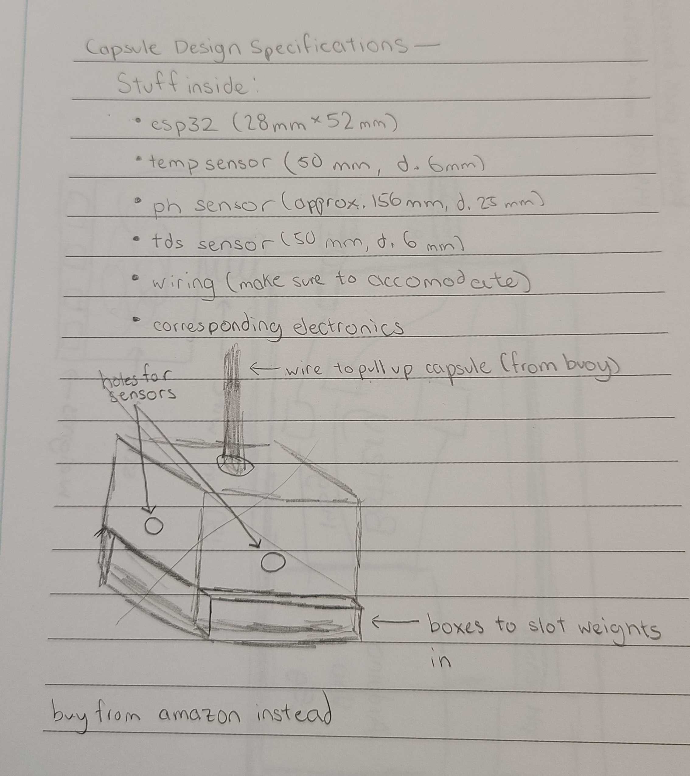
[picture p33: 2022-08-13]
2-buoy/Capsule/capsule_design_prototype.jpg

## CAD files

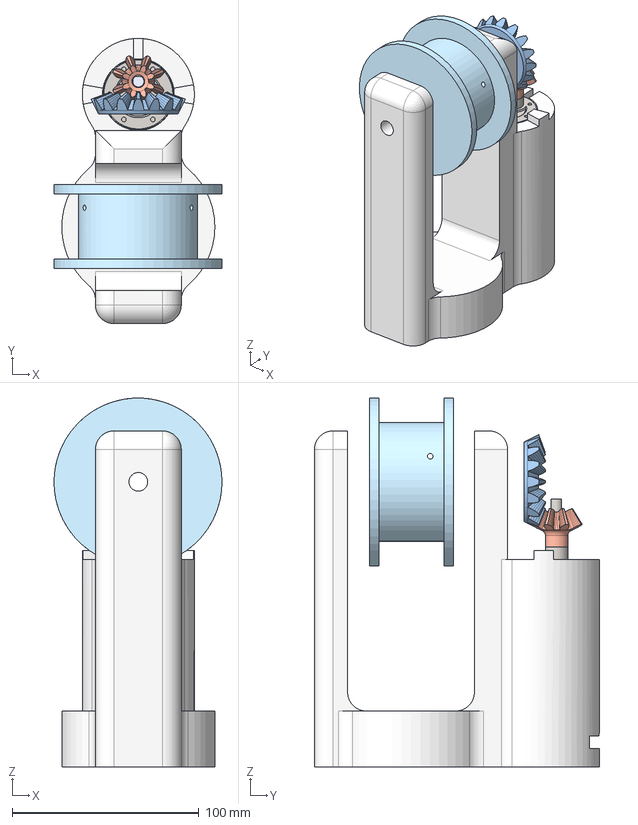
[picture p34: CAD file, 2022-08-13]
2-buoy/Buoy2/PostTestDay/General_Assembly.step
90.0 x 152.7 x 197.6 mm
Gear 1
Gear 2
am-2964a Neverest Classic 40

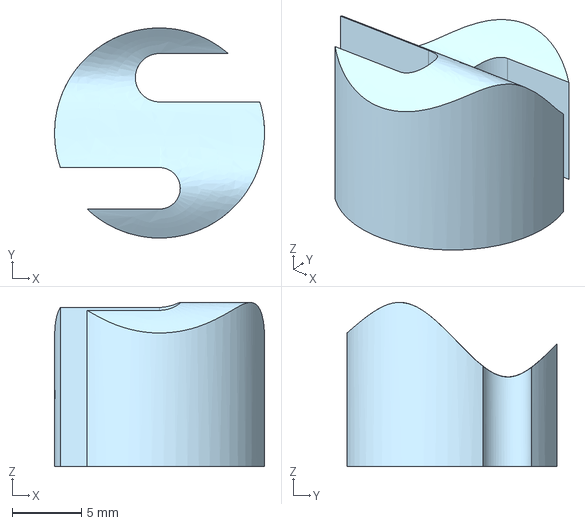
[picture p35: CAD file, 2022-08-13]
2-buoy/Buoy1/TDS and PH wire holder - top.step
15.2 x 15.2 x 11.9 mm

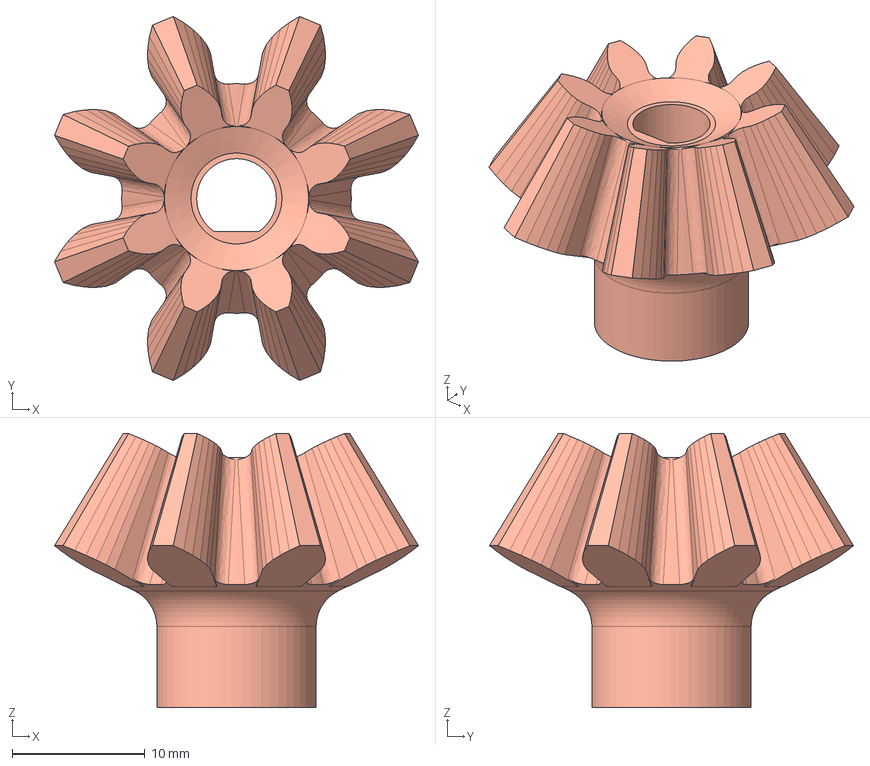
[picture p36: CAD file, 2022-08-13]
2-buoy/Buoy2/PostTestDay/Gear_1_1.step
27.4 x 27.4 x 20.6 mm

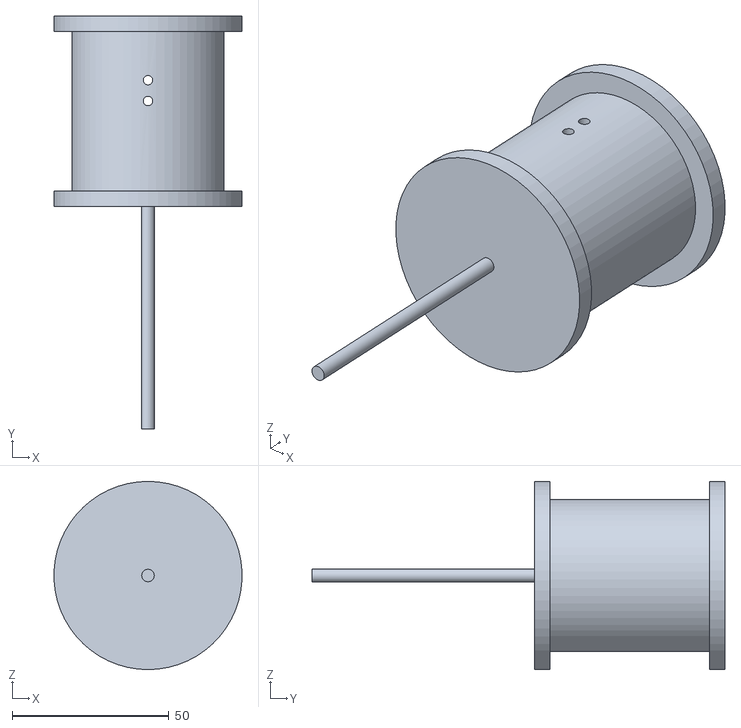
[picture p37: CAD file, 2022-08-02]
2-buoy/Buoy2/Spool Wheel (1).stl
59.9 x 131.7 x 60.0

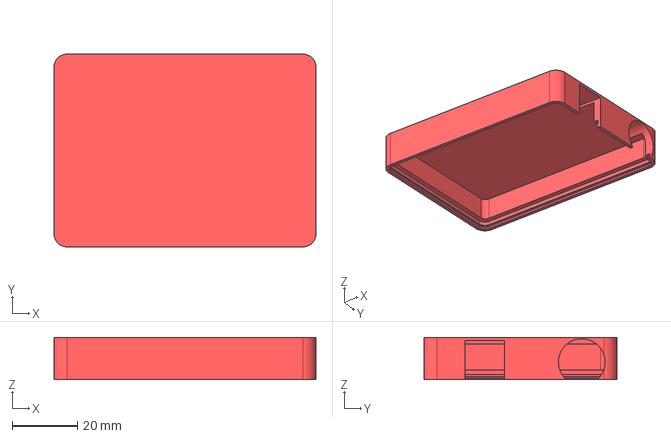
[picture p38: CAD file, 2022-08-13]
2-buoy/Capsule/Arduino Uno Case - Top.step
80.6 x 59.3 x 13.0 mm

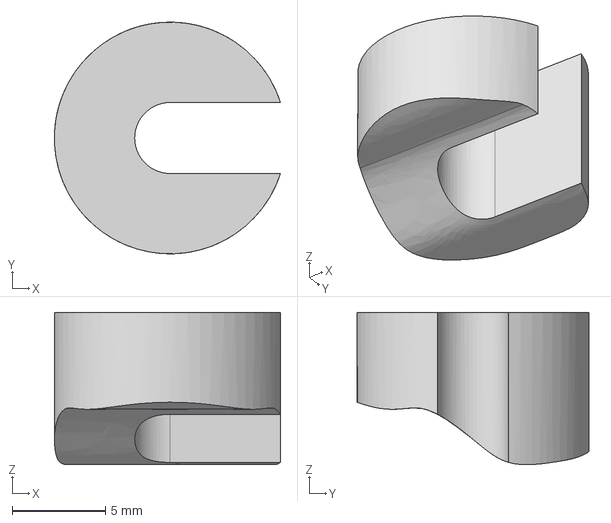
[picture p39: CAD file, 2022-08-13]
2-buoy/Buoy1/Temp holder - top.step
12.1 x 12.4 x 8.15 mm

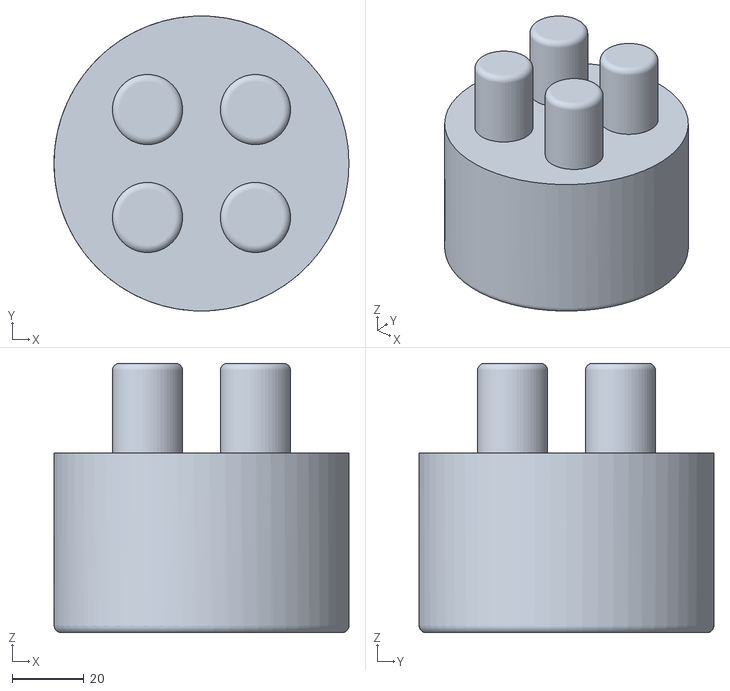
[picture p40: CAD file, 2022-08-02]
2-buoy/Buoy2/(Final) Cup Holder Piece (3).stl
82.0 x 82.0 x 74.9

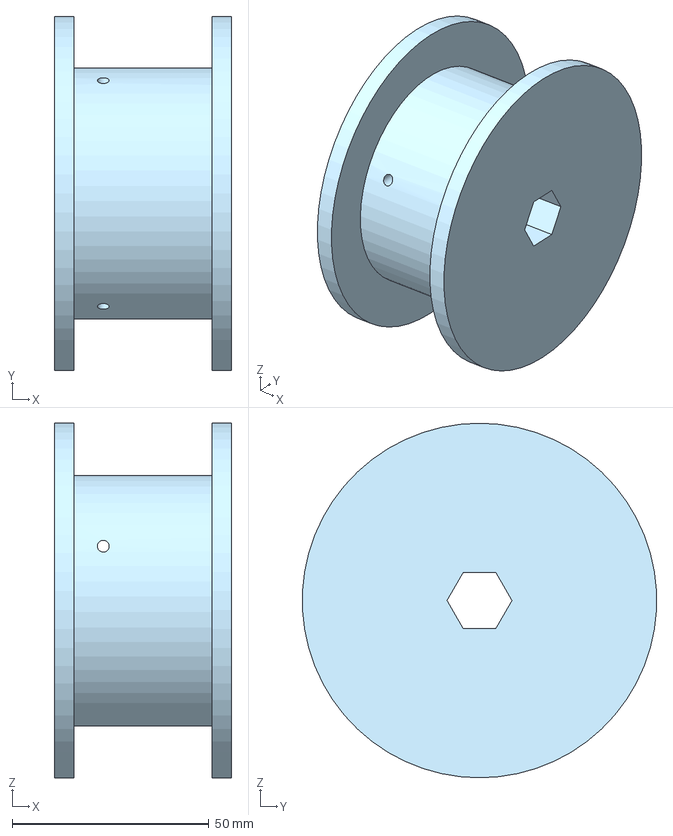
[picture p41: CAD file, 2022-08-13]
2-buoy/Buoy2/PostTestDay/Spool.step
45.0 x 89.9 x 90.0 mm

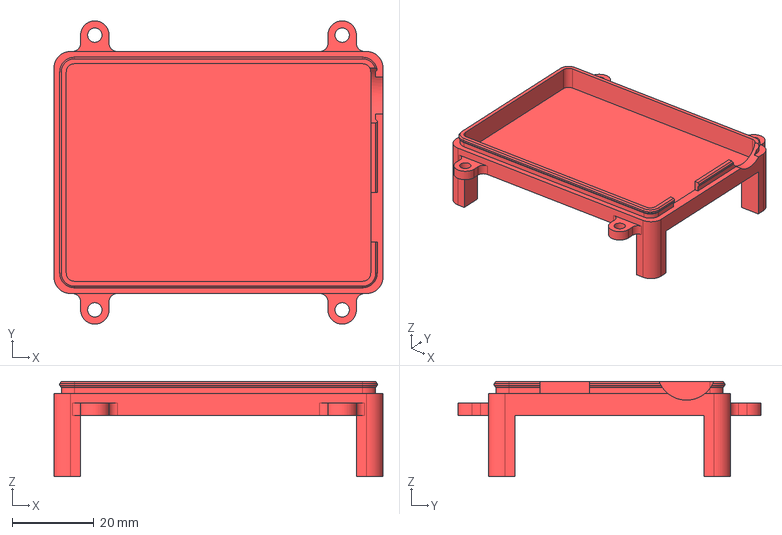
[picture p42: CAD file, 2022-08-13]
2-buoy/Capsule/Arduino Uno Case - Bottom.step
80.6 x 74.3 x 23.3 mm

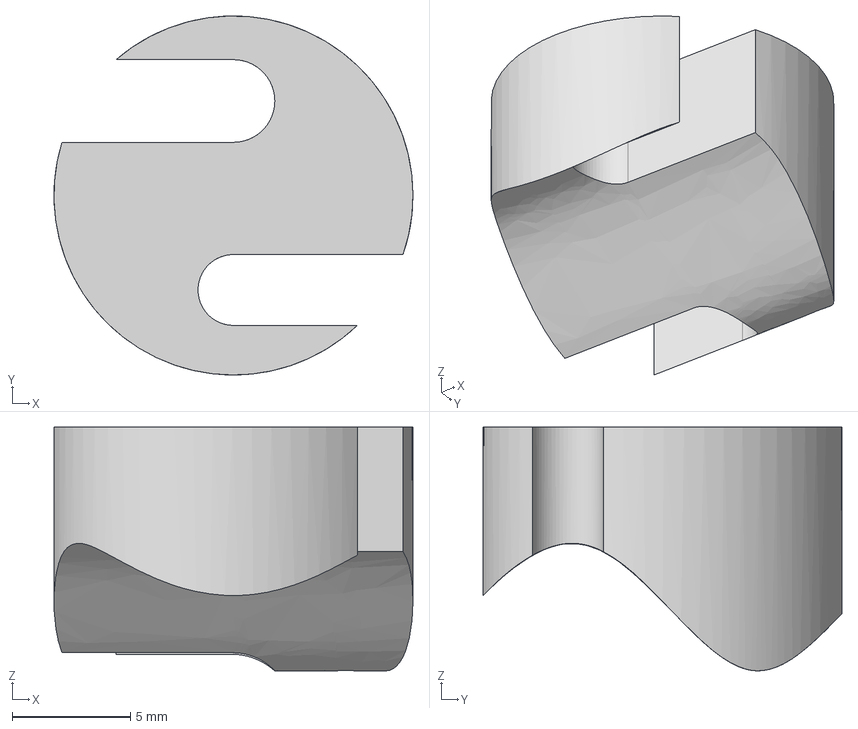
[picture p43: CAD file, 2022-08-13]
2-buoy/Buoy1/TDS and PH wire holder - bottom.step
15.2 x 15.2 x 10.3 mm

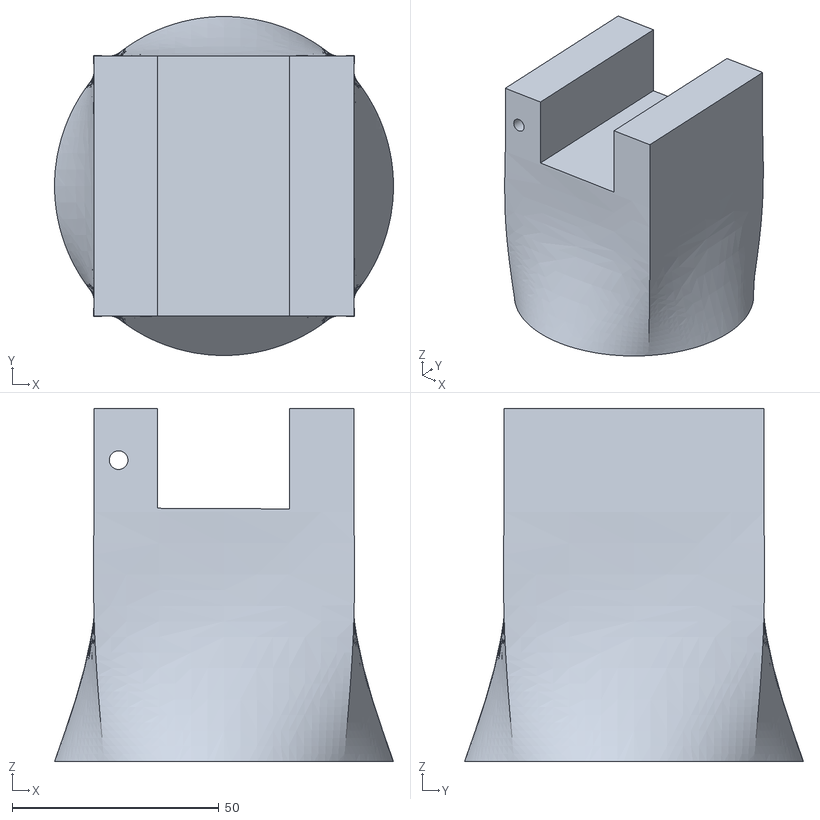
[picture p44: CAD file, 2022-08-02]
2-buoy/Buoy2/Spool Holder v1 (1).stl
82.0 x 82.0 x 85.4

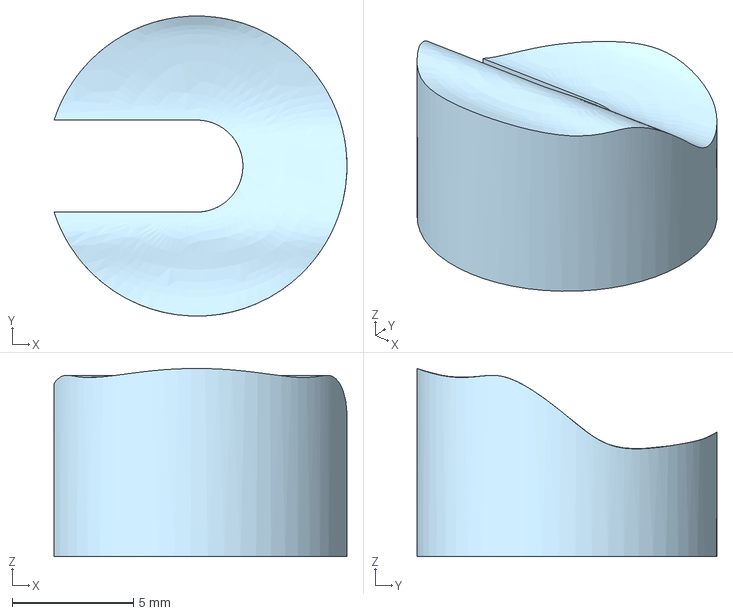
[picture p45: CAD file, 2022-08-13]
2-buoy/Buoy1/Temp holder - bottom.step
12.1 x 12.4 x 7.77 mm

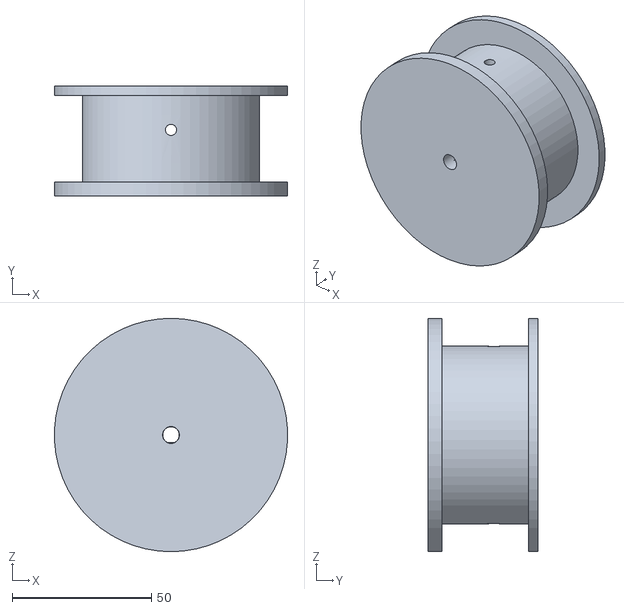
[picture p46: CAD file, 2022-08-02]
2-buoy/Buoy2/Final Spool Wheel (1).stl
83.5 x 39.6 x 83.7

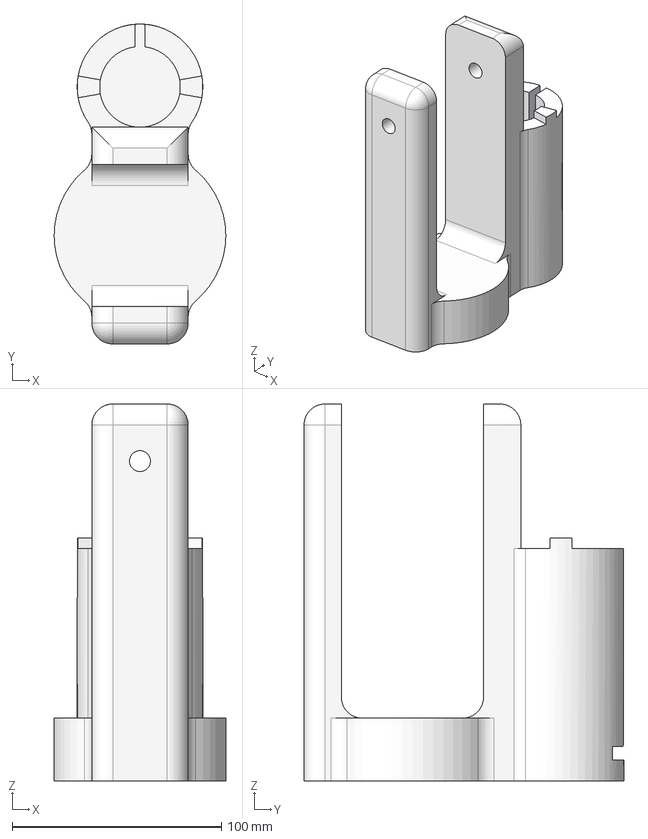
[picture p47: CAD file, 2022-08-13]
2-buoy/Buoy2/PostTestDay/Motor_Casing_Structure (1).step
82.0 x 152.7 x 180.0 mm

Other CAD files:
2-buoy/Buoy1/Ph sensor.step
2-buoy/Buoy1/Spool holder first iteration.step
2-buoy/Buoy1/TDS Sensor base.step
2-buoy/Buoy1/Motor_Casing_Attachment_Lego_Adapter.step
2-buoy/Buoy1/Spool wheel first iteration.step
2-buoy/Buoy1/TDS sensor enclosure.step
2-buoy/Buoy1/Temperature holder.step

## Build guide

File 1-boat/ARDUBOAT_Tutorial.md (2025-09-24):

@@ -1,376 +0,0 @@
# Arduboat Tutorial

Created by Justin

After two weeks and four days of shorts and software struggles, we were given a different flight controller for our boat. This is a compilation of a single day of work the day before the final field test. Below is a step-by-step guide to building your own autonomous boat. Hope this helps!

1. **RC Boat**

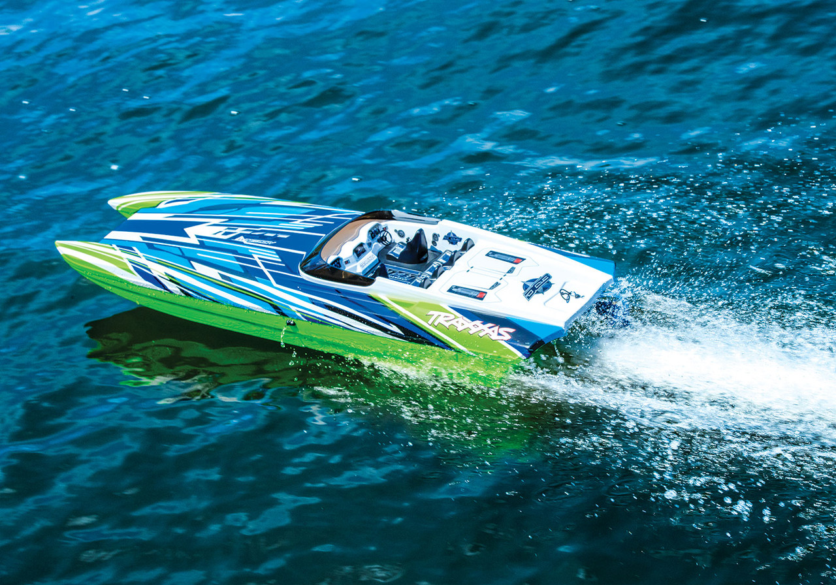
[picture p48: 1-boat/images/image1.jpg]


Our group used the [Traxxas m41 widebody](https://traxxas.com/products/models/marine/DCBM41) as the main body of the boat. This is a replica of a racing boat and is capable of speeds over 50 mph. But our boat will be moving at much slower speeds to collect oceanographic data.

2. **Flight controller**

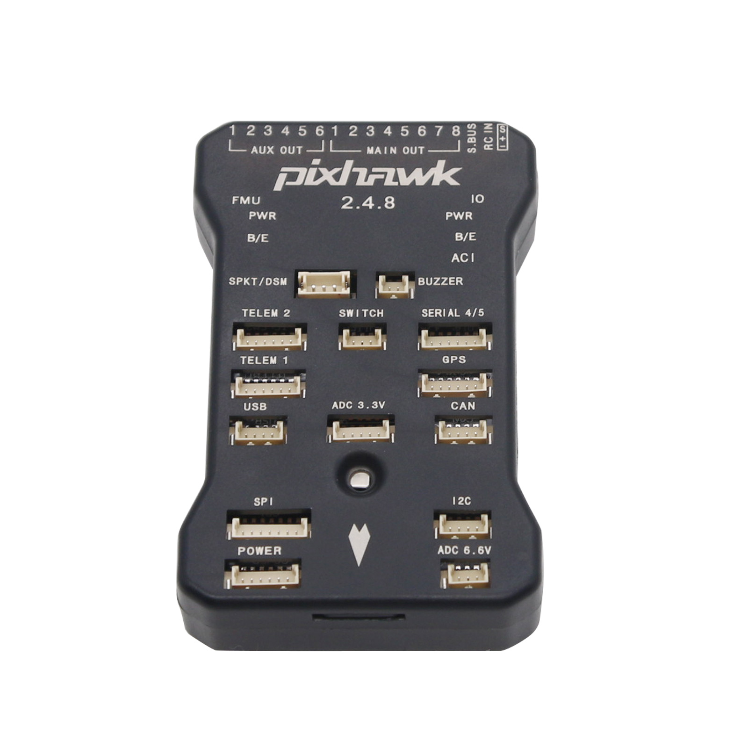
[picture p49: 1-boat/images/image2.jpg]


The flight controller we used on the final boat was a pixhawk 2.4.8. Since the firmware on this device is a bit older, we must update the firmware with QGroundControl.

QGroundControl: [https://docs.qgroundcontrol.com/master/en/getting_started/download_and_install.html](https://docs.qgroundcontrol.com/master/en/getting_started/download_and_install.html)

This will allow us to easily update the firmware on the Pixhawk and other hardware that we will be using later.

Open QGroundControl -> Select Tool -> Vehicle Setup -> Summary -> Firmware (Unplug then plug in pixhawk) -> Settings

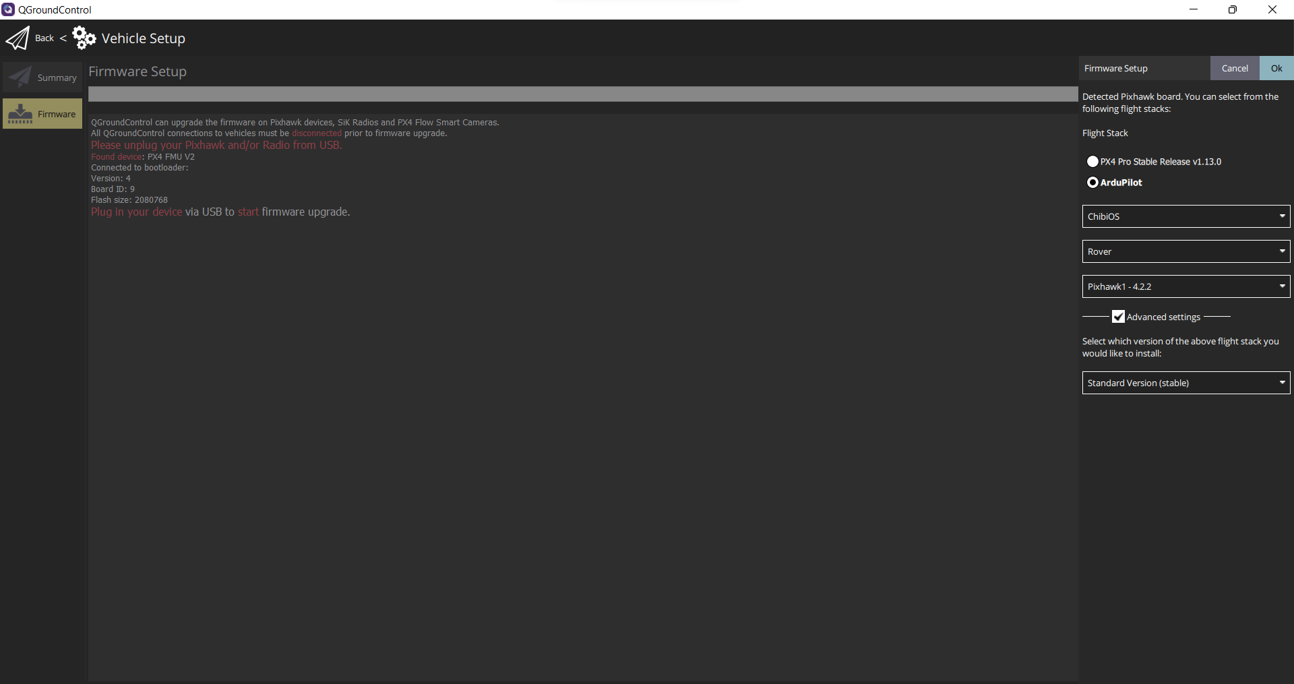
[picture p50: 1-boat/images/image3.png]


3. **Software**

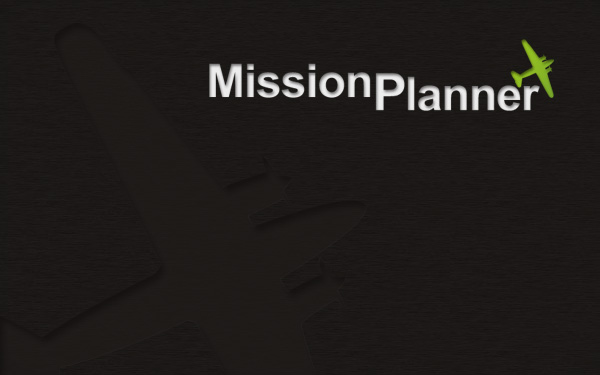
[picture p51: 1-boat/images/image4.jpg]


Our flight controller will be running on Ardupilot, which is an open source firmware for drones. Mission Planner is the ground control system for Ardupilot where we will be communicating with the flight controller.

Mission Planner: 

[https://ardupilot.org/planner/docs/mission-planner-installation.html#](https://ardupilot.org/planner/docs/mission-planner-installation.html#)

To connect the flight controller to Mission Planner, make sure to use a data usb cable, not a power only cable. Power only cables will not allow the controller to connect.

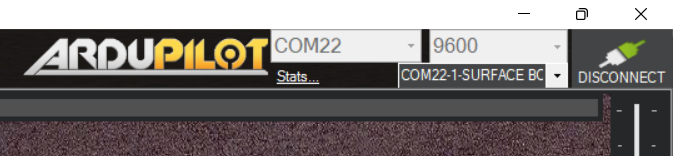
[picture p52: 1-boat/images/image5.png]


To connect, first check all the available ports in the dropdown menu, then plug in the controller and select the new option that pops up. Set the baud rate in the next dropdown as 9600 since we are on a serial connection currently. Click connect and wait for the flight controller to make a connection.

If you have COM port issues, download these virtual COM Port drivers for your computer.

[https://ftdichip.com/drivers/vcp-drivers/](https://ftdichip.com/drivers/vcp-drivers/)

Now you should be able to see the movement of the flight controller in the left hand panel.

To set the flight controller as a boat, go to 

_Setup -> Full Parameter List -> Search FRAME_CLASS -> Set as 2_

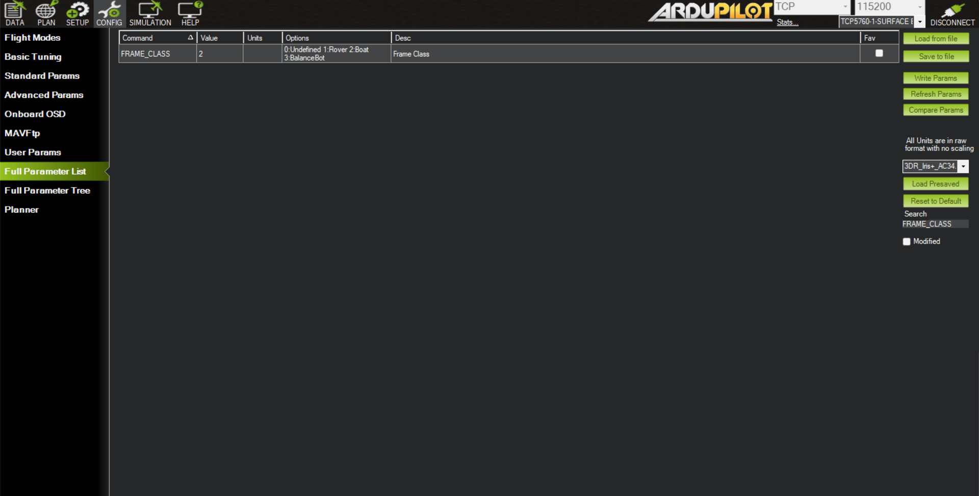
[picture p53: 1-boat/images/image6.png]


4. **Radios**

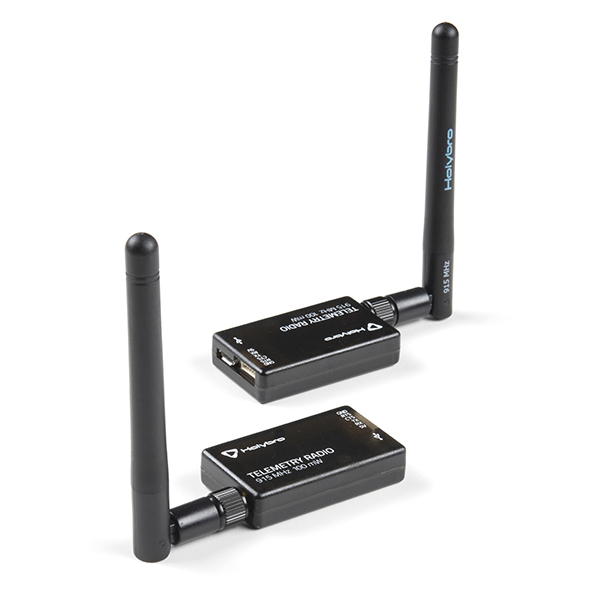
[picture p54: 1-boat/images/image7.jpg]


The radios we used were SiK 915 MHz, which has a baud rate of 57600. To connect these to the flight controller, plug one radio into TELEM1 on the pixhawk and one into the computer through USB.

Now to connect the radios, click 

_Setup -> Optional Hardware -> SiK Radio_

Now click load settings and the settings should appear in Mission Planner.

If the settings are not loading, connect the radios by USB to QGroundControl and update the firmware.

_Select Tool -> Vehicle Setup -> Summary -> Firmware (Unplug then plug in Pixhawk) -> Settings_

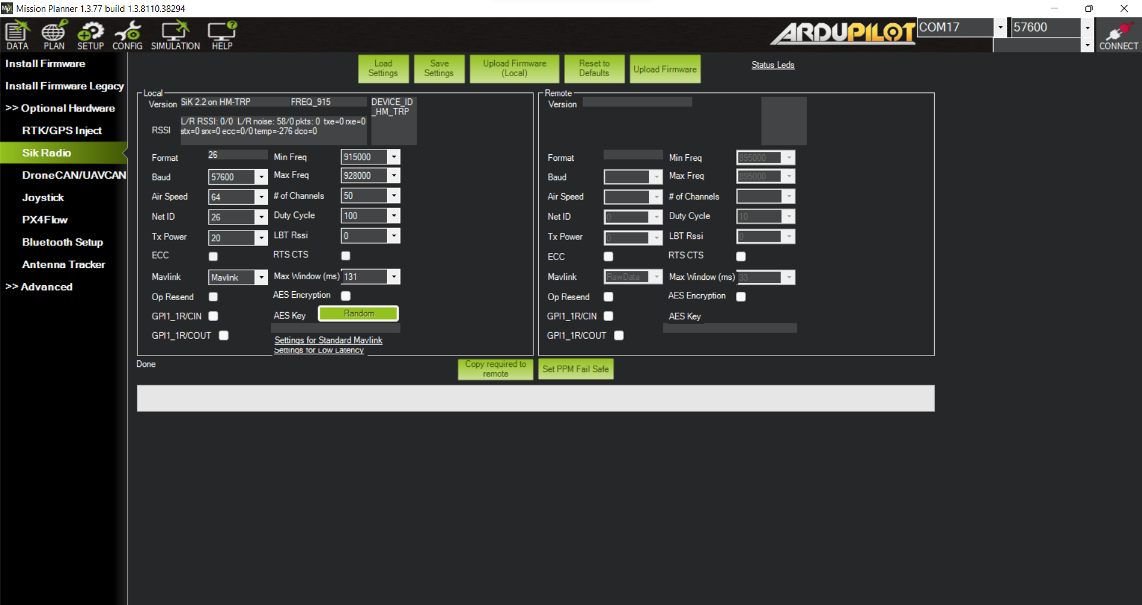
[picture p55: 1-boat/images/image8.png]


5. **GPS/Compass**

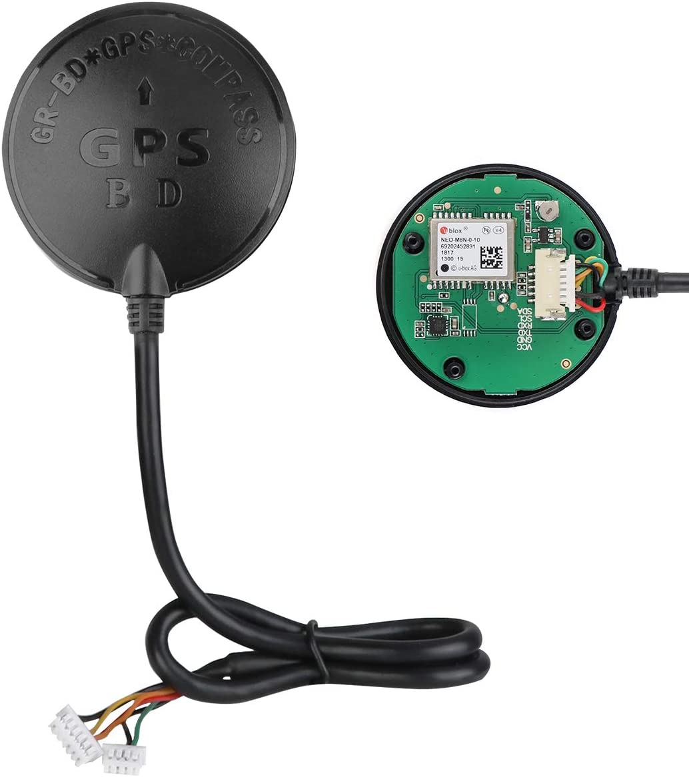
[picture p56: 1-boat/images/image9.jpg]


We used the _GPS Module GPS NEO-M8N BDS Compass Module_ as our gps and compass. Plug in the larger adapter into the GPS slot and the smaller in the I2C on the Pixhawk.

Open Mission Planner and connect the Pixhawk.

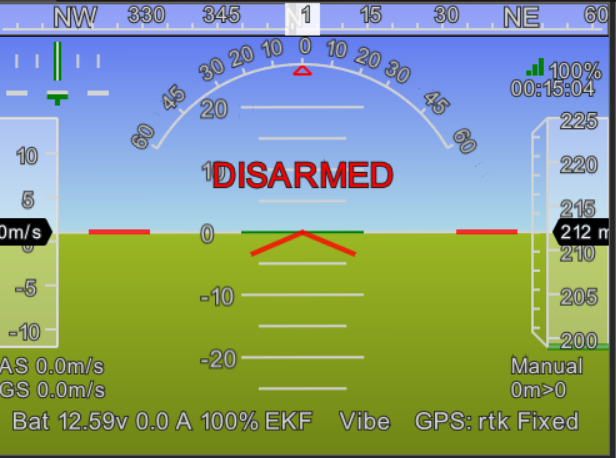
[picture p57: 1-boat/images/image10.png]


Indoors, the GPS will not fix on the satellite, so you must go outdoors in at least a semi-open space for a fix. Now, the GPS should be functioning.

To calibrate the compass, open Mission Planner and connect the Pixhawk, and go to

_Data -> Setup -> Mandatory Hardware -> Compass -> Follow the steps for calibration_

It will ask you to move the compass in multiple directions for a bit.

Now the compass and GPS should work in ideal conditions.

We printed a GPS stand to attach it to the outside of the boat: [https://drive.google.com/file/d/1A_vzA1YP445HYMUqo_vrnWkr_7P-FACy/view](https://drive.google.com/file/d/1A_vzA1YP445HYMUqo_vrnWkr_7P-FACy/view)

6. Batteries

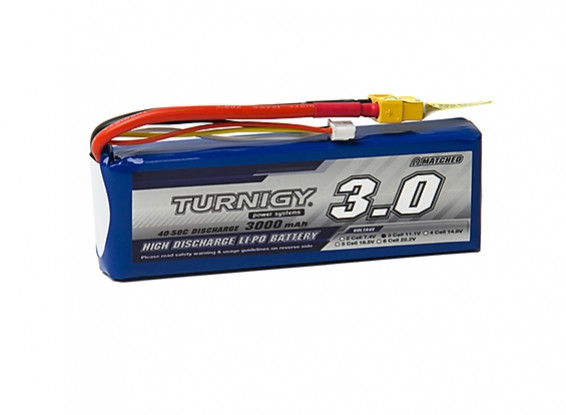
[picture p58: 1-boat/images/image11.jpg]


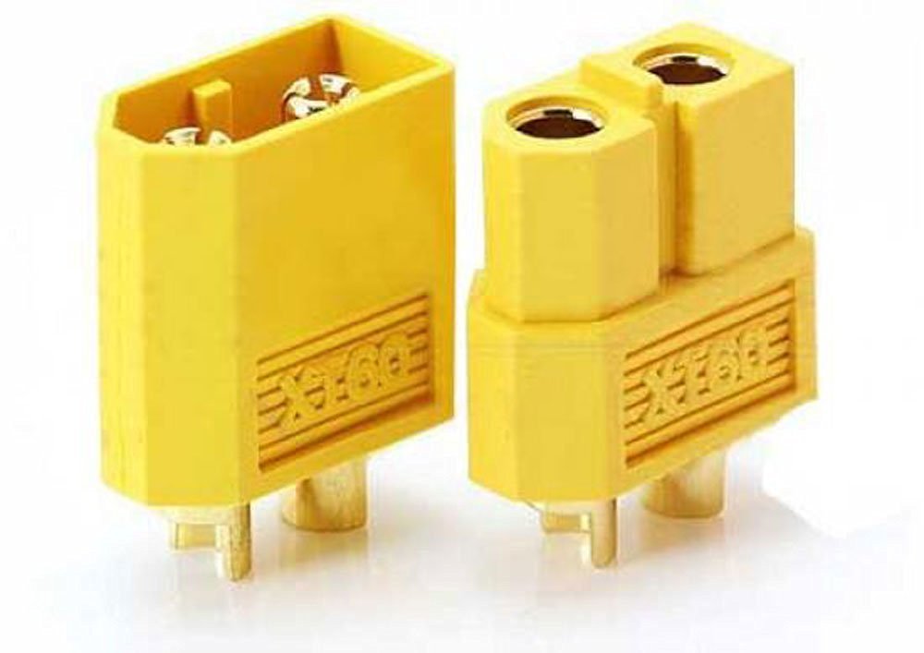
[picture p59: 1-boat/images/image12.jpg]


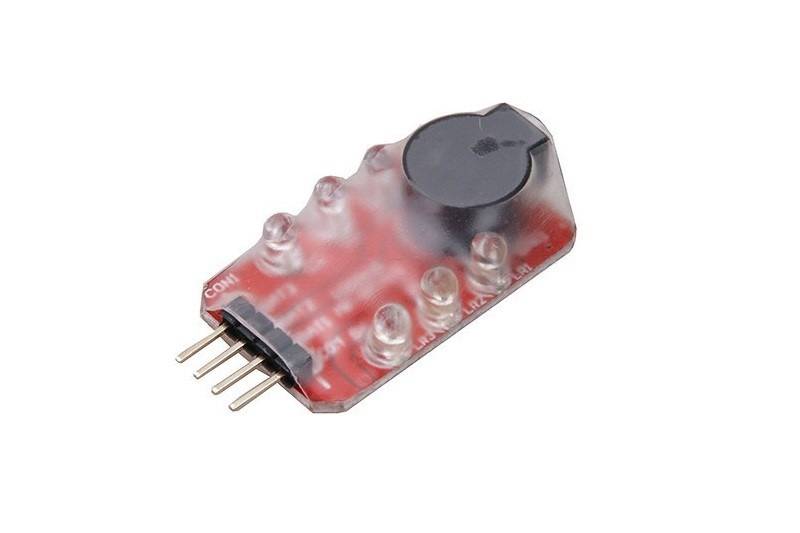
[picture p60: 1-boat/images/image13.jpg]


Traxxas has their own proprietary connectors, so we need to solder on new adapters (XT60) to fit the lipo batteries that we are using. In addition, we added battery alarms to each battery.

7. Motors + Servos

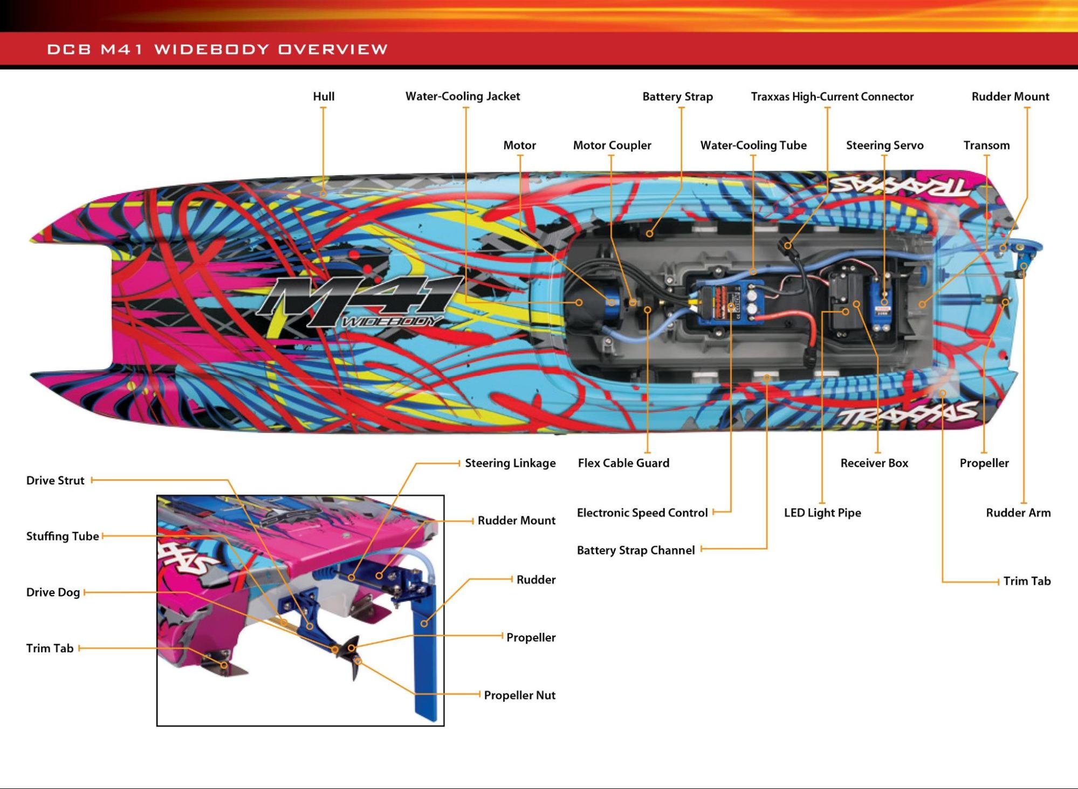
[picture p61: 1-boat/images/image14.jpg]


In order to make the boat autonomous, we must connect the Pixhawk to the ESC (connects to motor) and servo (rudder). This will allow us to control the throttle and steering through Mission Planner. 

First we need to remove the receiver box in the boat so we can override their messages.

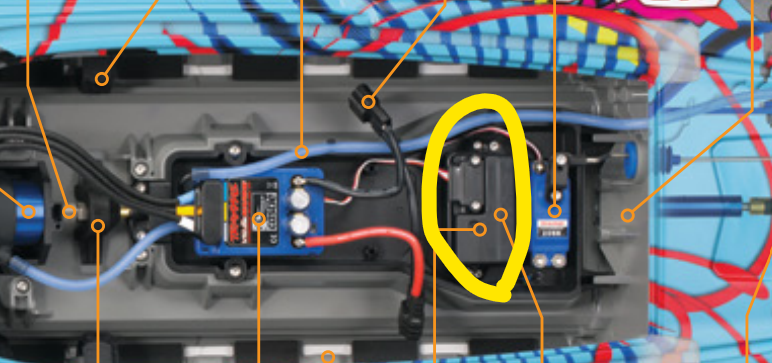
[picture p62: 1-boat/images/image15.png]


Remove the entire box with the receiver inside of it.

After that you should have two 3 pin wires: one from the ESC and one from the servo.

8. RC controller + receiver

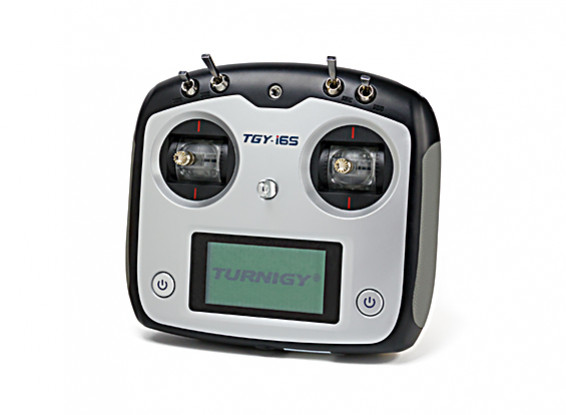
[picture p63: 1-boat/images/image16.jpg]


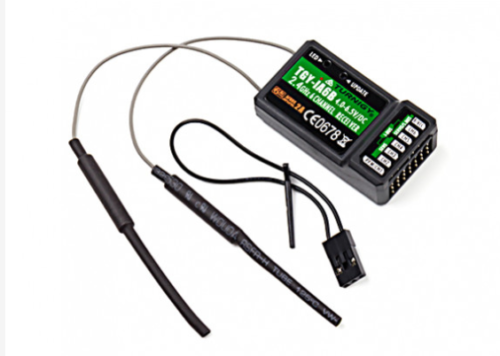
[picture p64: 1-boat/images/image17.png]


For any autonomous boat, we need a safety switch to change to manual control in case of any problems. To do this, we can attach a 3+ channel RC receiver to the pixhawk: one channel for throttle, another for steering, and another for changing between autonomous and manual mode. We used a TGY i65 controller with its receiver.

First we want to test just the RC receiver and the boat itself, so let's take the ESC pin and plug it into the first channel and the servo into the third. 

On the controller itself, make sure the channels of the two joysticks are set to the first and third so the boat will respond to the commands.

With the batteries plugged in, the ESC should go through a mario-kart-esque beeping sequence and stop. In case it doesn't, try binding the receiver with the controller: 

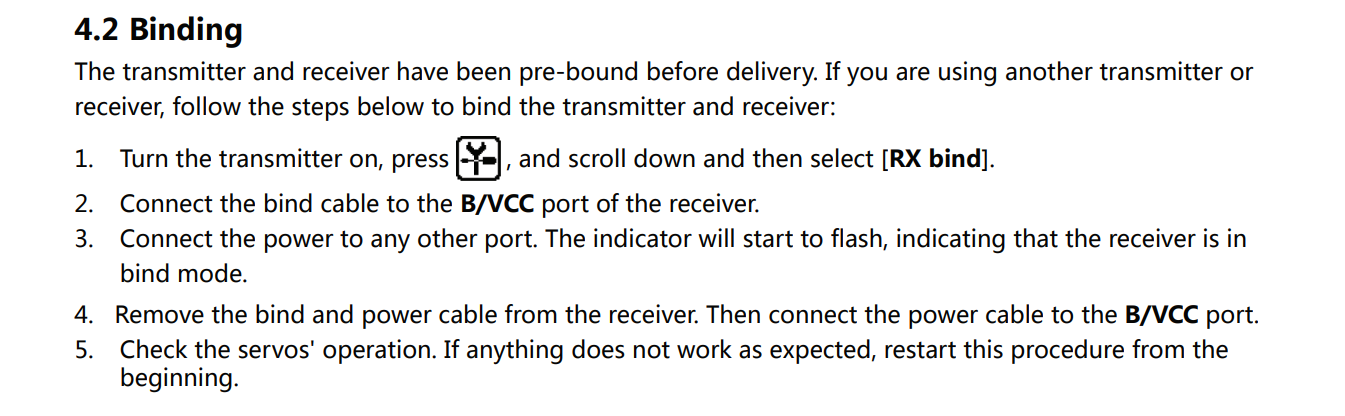
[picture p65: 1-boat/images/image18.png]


On the controller, go to Endpoints and set the both endpoints of the throttle to 50%. This will prevent the boat from driving at extreme speeds in a tightly confined pool, hopping over lanes and breaking propellers. 

This should not be a problem in open waters.

With the boat on a stand or with the rudder and prop hanging off the edge of a table, you can try the controls. It should be able to spin forward and backwards, as well as turn the rudder side to side. 

9. Rudders + Propellers

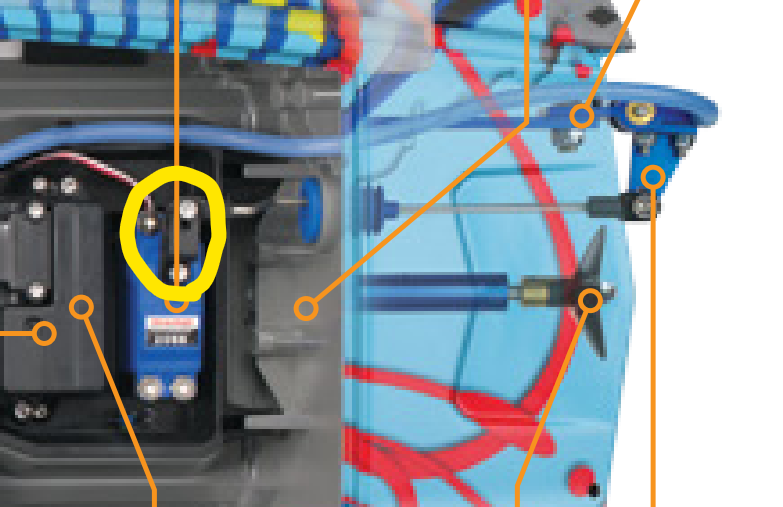
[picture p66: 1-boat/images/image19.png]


The rudder on the boat is meant for a fast moving craft, so for a slow moving craft, we must create a larger rudder for the same turning effectiveness.

The design of the boat causes the esc and motor to be water cooled by water pulled in from the rudder, so we must 3d print a new rudder that has the same holes. In addition, the current servo arm has a limited range, so we need to print a longer one for more range in the rudder.

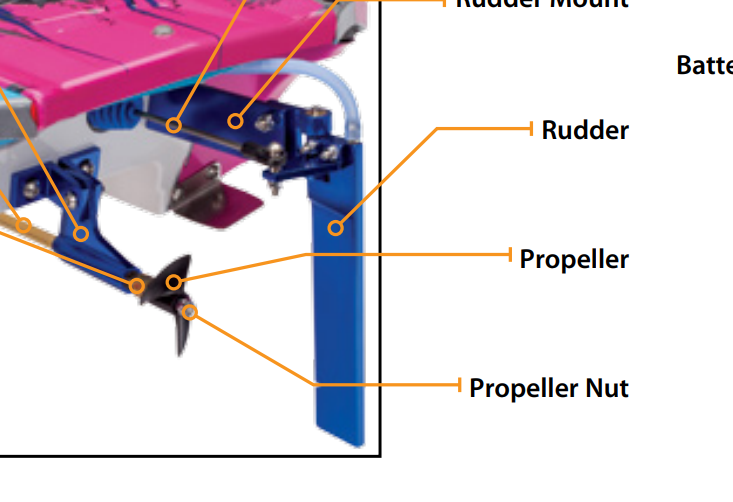
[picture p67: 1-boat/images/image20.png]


Here is the progression of designs for the rudder:

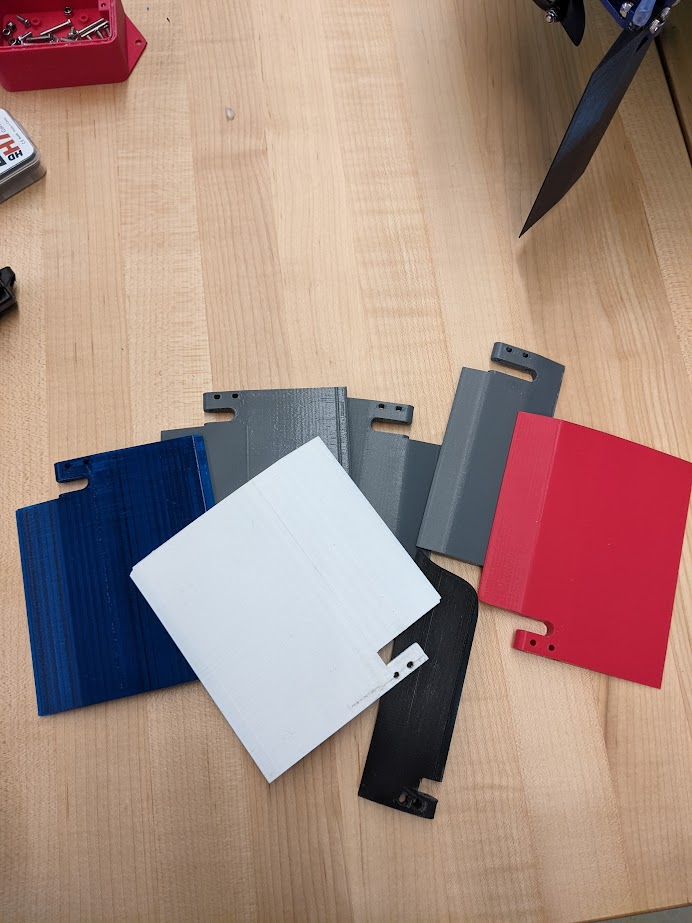
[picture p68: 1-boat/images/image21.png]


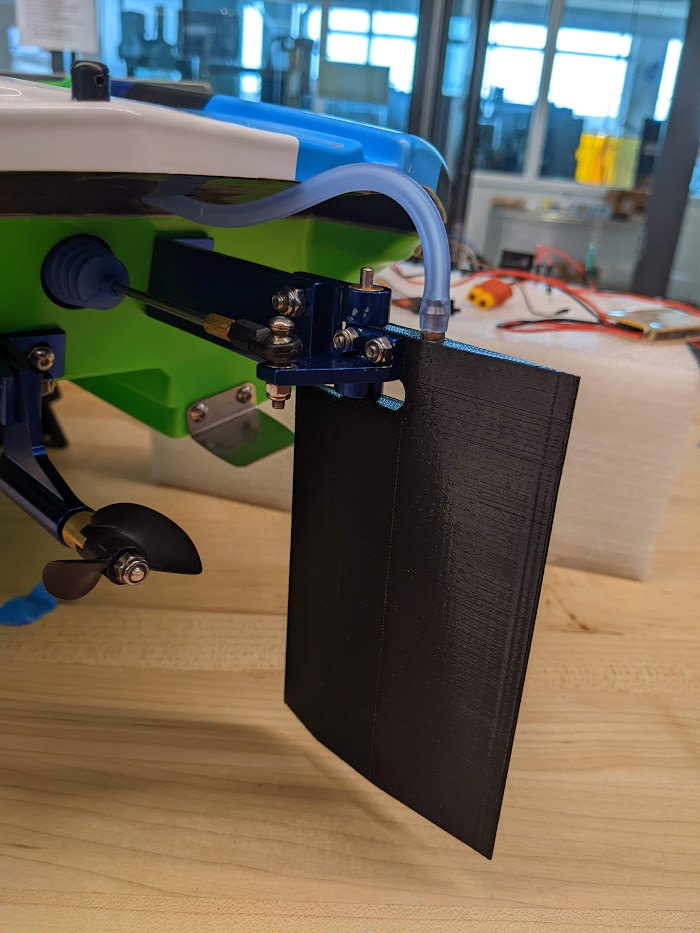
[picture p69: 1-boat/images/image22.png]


We eventually settled on the larger rudder with a few small design changes along the way. Here is the final design we used:

[https://cad.onshape.com/documents/341f0bfbb7fd9b8641d10de2/w/ccba5a872075a3eeead7d582/e/0432abc8975b2662196b00e9](https://cad.onshape.com/documents/341f0bfbb7fd9b8641d10de2/w/ccba5a872075a3eeead7d582/e/0432abc8975b2662196b00e9)

For the servo arm, we used a similar design to the original and increased the length incrementally until we reached the final design.

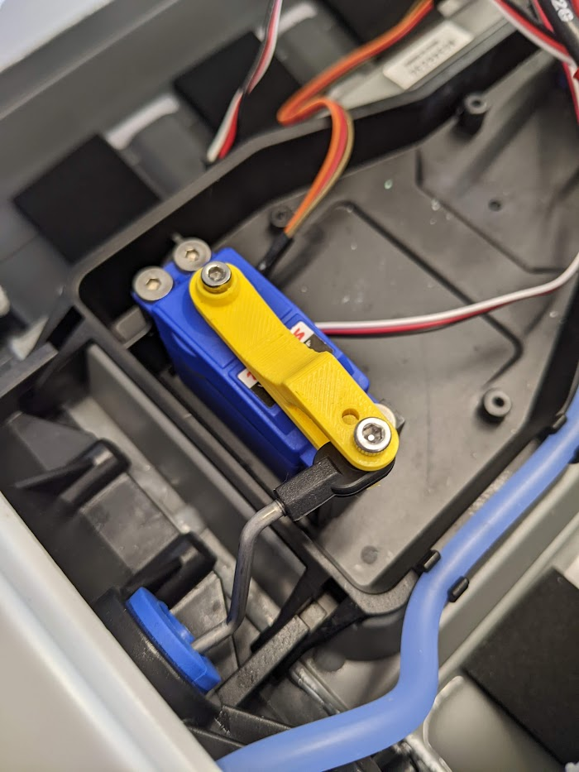
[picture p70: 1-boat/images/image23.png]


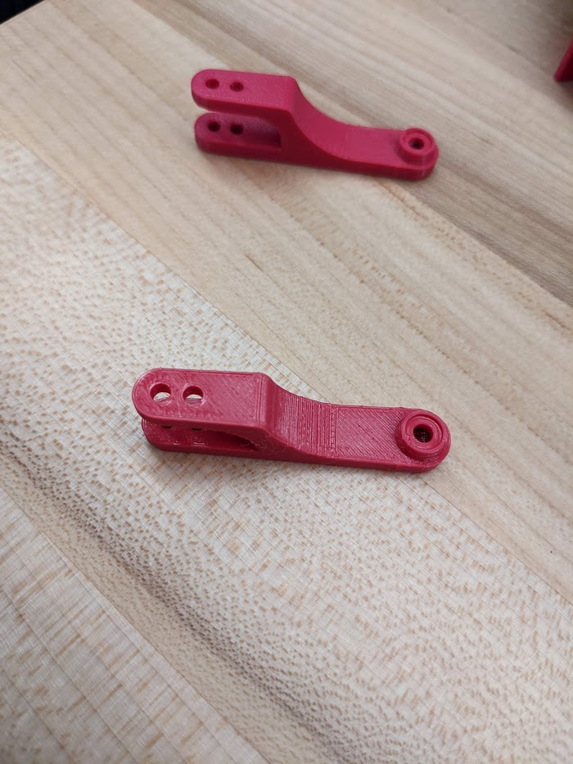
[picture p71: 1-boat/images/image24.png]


Here is the link to the final servo arm design: [https://cad.onshape.com/documents/2f5a1ff8fc77d09ff0f33b28/w/96a95d3afae6904bacc3db46/e/c4438d96de7ada338bfaa74e](https://cad.onshape.com/documents/2f5a1ff8fc77d09ff0f33b28/w/96a95d3afae6904bacc3db46/e/c4438d96de7ada338bfaa74e)

10. 3D printed boxes

Most of the electronics are not waterproof or water resistant, so we must put them in boxes or add a water resistant coating to them. For the radios, pixhawk, and rc receiver, we printed boxes for them. 

Pixhawk Container: [https://cad.onshape.com/documents/f0dcd2dc360e6153a8aceb5b/w/83c42524679d51935942d68b/e/775b05789a6a2d5d23418cd0](https://cad.onshape.com/documents/f0dcd2dc360e6153a8aceb5b/w/83c42524679d51935942d68b/e/775b05789a6a2d5d23418cd0)

Radio Container: [https://cad.onshape.com/documents/cbe6cff6ed3df61fe2a0e150/w/ee1321990144475658df51f7/e/609a2fe643e35127236df8c1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](https://cad.onshape.com/documents/cbe6cff6ed3df61fe2a0e150/w/ee1321990144475658df51f7/e/609a2fe643e35127236df8c1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)

RC receiver container:

[https://cad.onshape.com/documents/975f2f7a7f84f6e907830d6b/w/4012b4122810d31c85e447a8/e/c716113e8b8c94d3e3576a56](https://cad.onshape.com/documents/975f2f7a7f84f6e907830d6b/w/4012b4122810d31c85e447a8/e/c716113e8b8c94d3e3576a56)

On the other hand, the GPS was on the outside of the boat, so we gave it multiple coats in a silicon coating to make it water resistant.

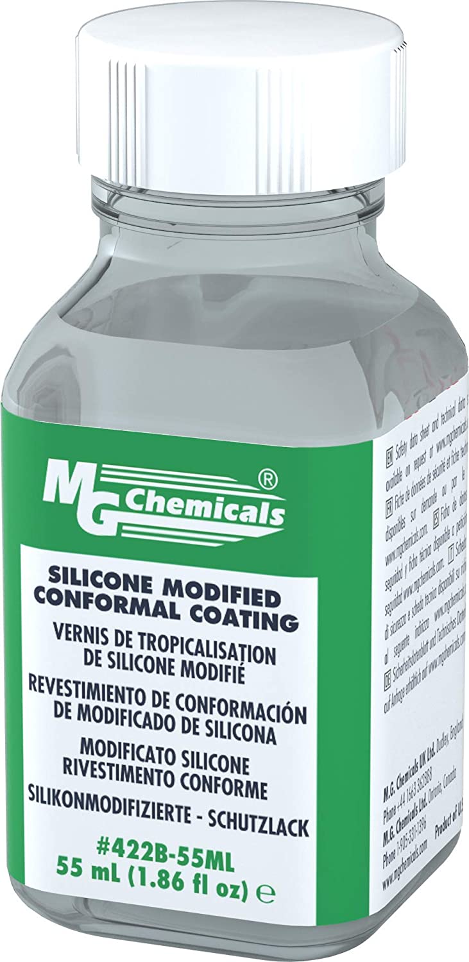
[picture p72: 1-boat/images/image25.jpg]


With these boxes and sealant, we should be safe when any water splashes into the boat.

11. **Putting it together**

Now that we have all the components of the boat working, we can link it all together. 

Power on the boat, and then plug the ESC pin into Main3 and the servo pin into Main2 on the Pixhawk. Now connect one radio into the pixhawk and one in the computer. Hopefully, the radios both have solid green lights, which means that they are connected. If not, that is ok and we can fix it later.

Now open Mission Planner and select the COM port and set the baud rate to 57600, which is what our radios use. Now click connect. If it connects, it will take a few seconds for the radios to completely link together. 

If not, click cancel and try again or change the COM port to auto. If it still persists after several attempts, try a different USB port on the computer.

Now to setup the motor and servo go to 

_Setup -> Mandatory Hardware -> Servo Output_

Set 2 to Ground Steering and 3 to throttle

You can change the turn radius and motor speed with the min, max, and trim values on the side.

Now go back to Data and click the actions tab in the bottom left panel

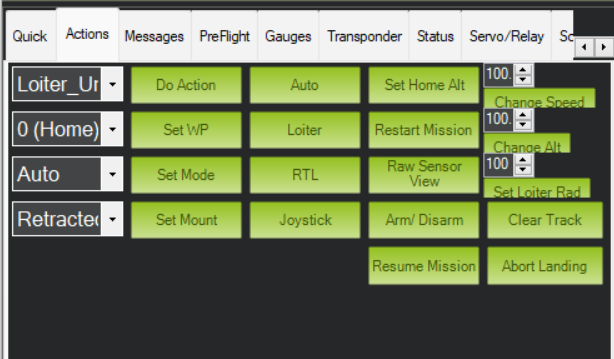
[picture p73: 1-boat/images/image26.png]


From here click Arm to arm the boat

Now to test, go to 

_Setup -> Optional Hardware -> Motor Test_

Make sure to set the value of the throttle to at least 15% from the default 5%. Motor A should be the throttle and motor B should be the rudder. To test the rudder, set the throttle to 100% and -100% to test the full range of the rudder.

Now we will test the radio control.

Plug a 3 pin connector from RC IN on the rc receiver to S-BUS slot in the top right

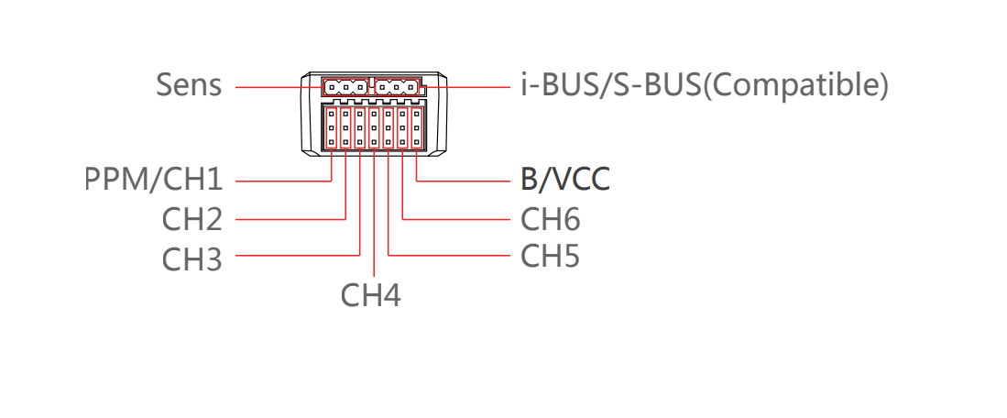
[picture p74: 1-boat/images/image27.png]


Next, 

_Setup -> Mandatory Hardware -> Radio Calibration _

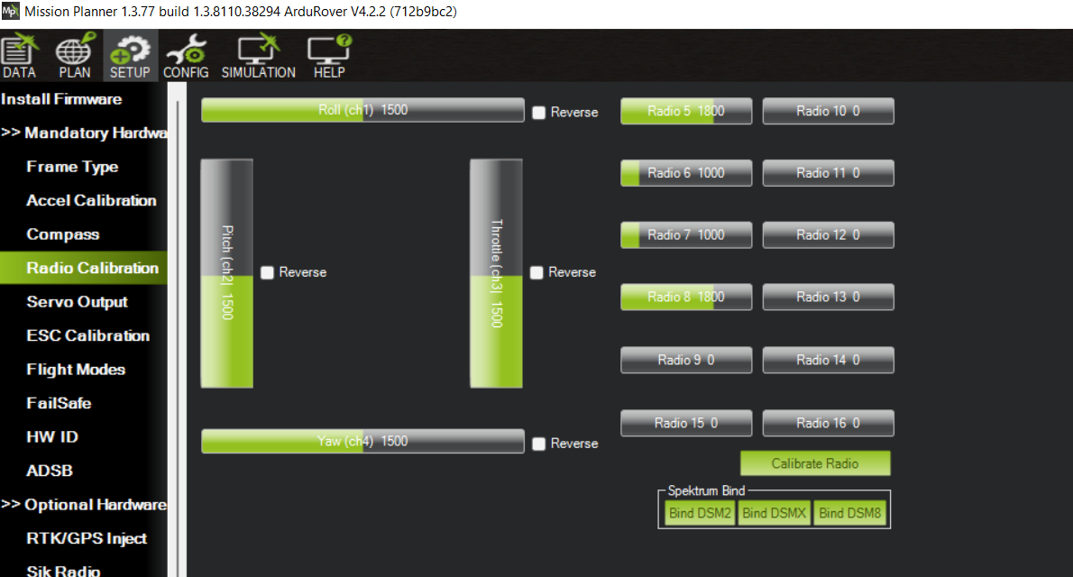
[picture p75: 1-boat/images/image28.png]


Make sure the channels are correct. Now, to switch to manual mode, use the switch in the top left(radio 6). It has two modes: the flipped down mode should be manual control and the upwards one should be auto.

Now go to the main page again and arm the boat, then flip the switch to manual.

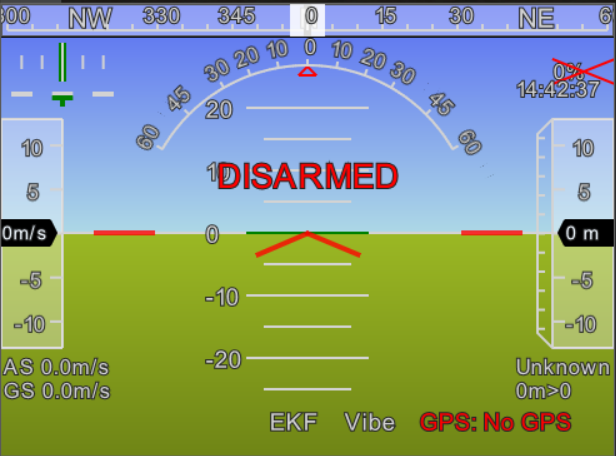
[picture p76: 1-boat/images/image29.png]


Now test the boat and the RC should be functioning.

12. Path planning + automation

To create a path, go to the Plan Tab, and if the GPS is connected, you should see a boat at your current location.

Now you can click on points for the boat to follow. For our boat, we want it to stop at certain locations for a set amount of time, and we can do that with the LOITER_TIME function. This tells the boat to hover in a certain place for a set time.

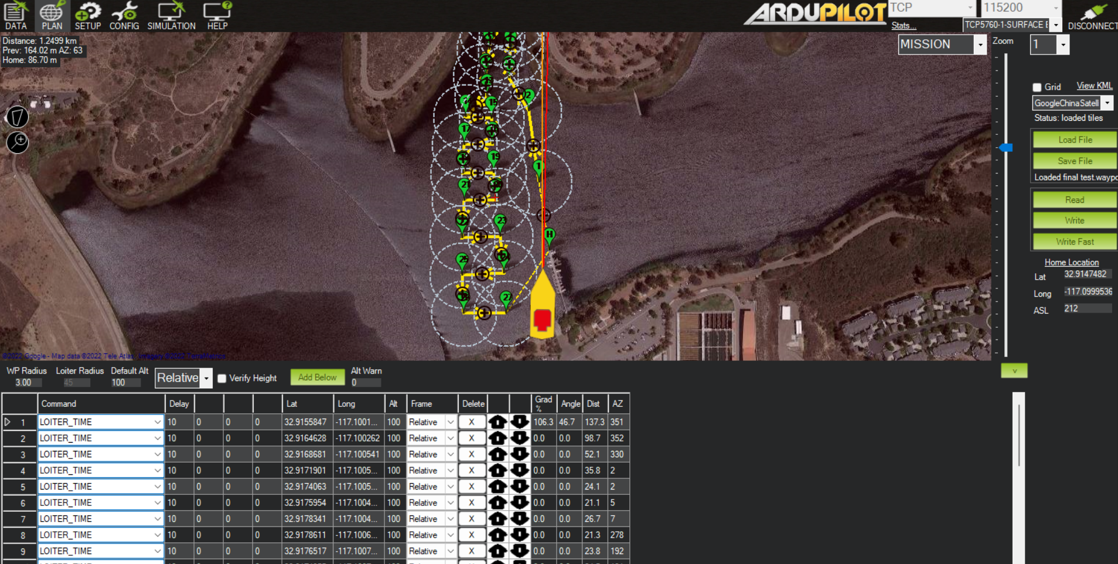
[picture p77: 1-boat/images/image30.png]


To save the file, press save file on the right, and you can load in the file anytime you want.

Now to test the automation, create a short path from your location, and click the write button. This will write the waypoints into the flight controller so it knows where to go. 

Now go back to the Data page and select the actions tab. Now change the first default dropdown to MISSION_START

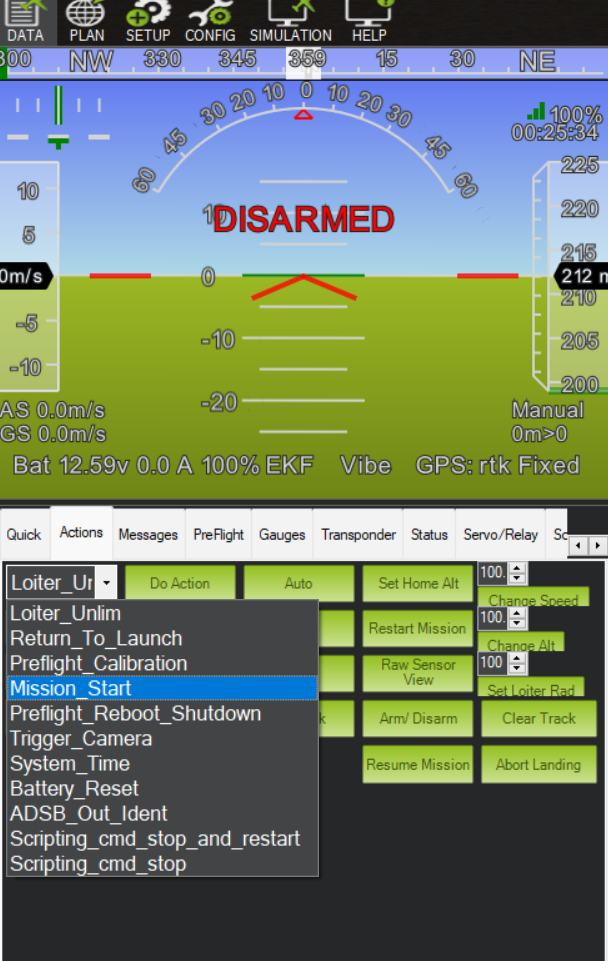
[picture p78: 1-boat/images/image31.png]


Now arm the boat, and then click the **Do Action** Button.

If the rudder is inverted go to the servo output page and click reverse. Make sure to test the min, max, and trim of the throttle for a good speed.

13. Done!

Thanks for reading through! Hope this helps you on your journey of making an autonomous boat.

* Justin and Buddies
14. Pictures!

Team members!

Justin Leong

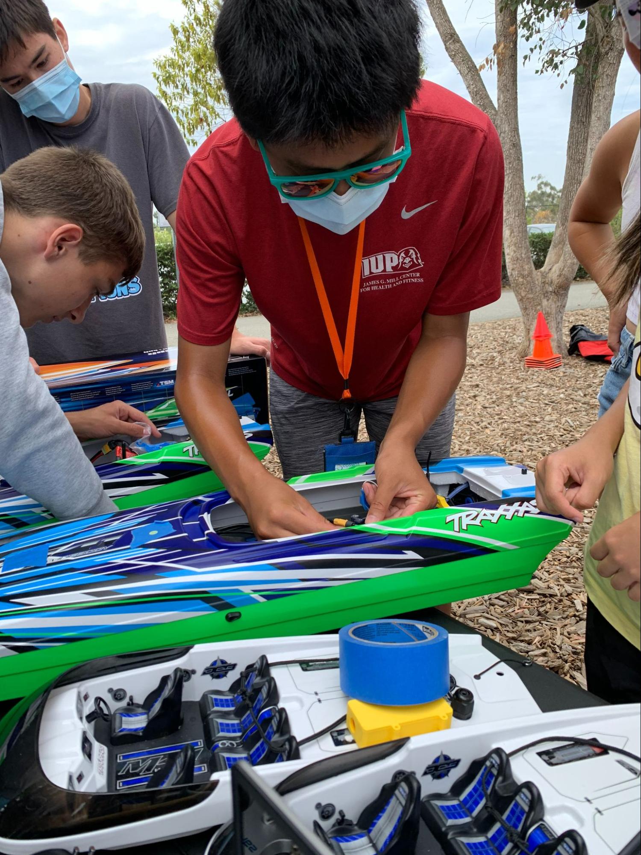
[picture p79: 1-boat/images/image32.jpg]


Josh Tian

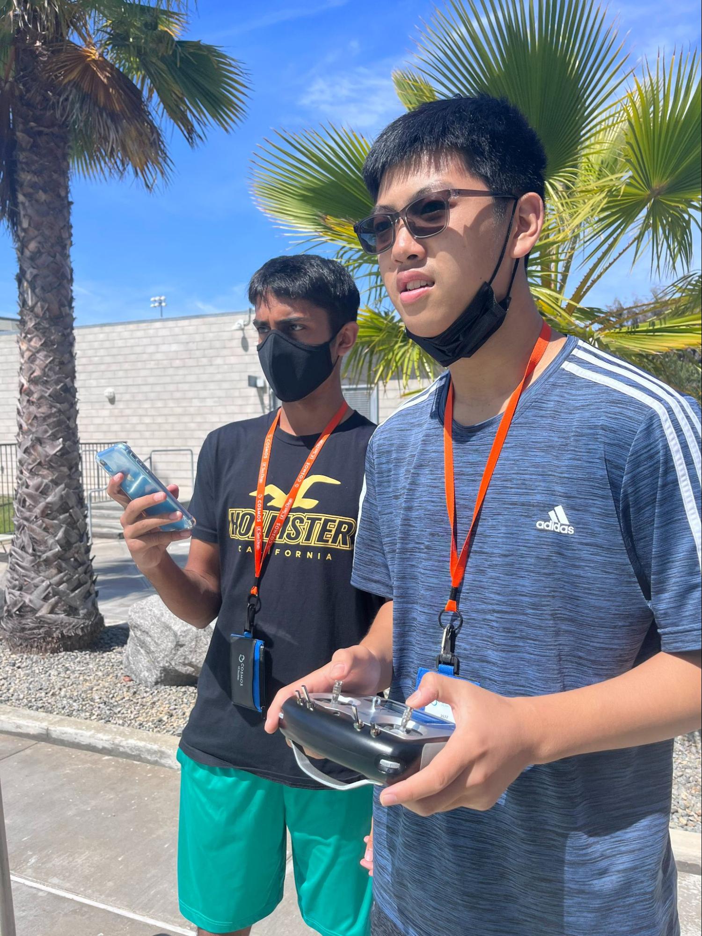
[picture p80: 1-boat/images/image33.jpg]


Saarth Gaonkar

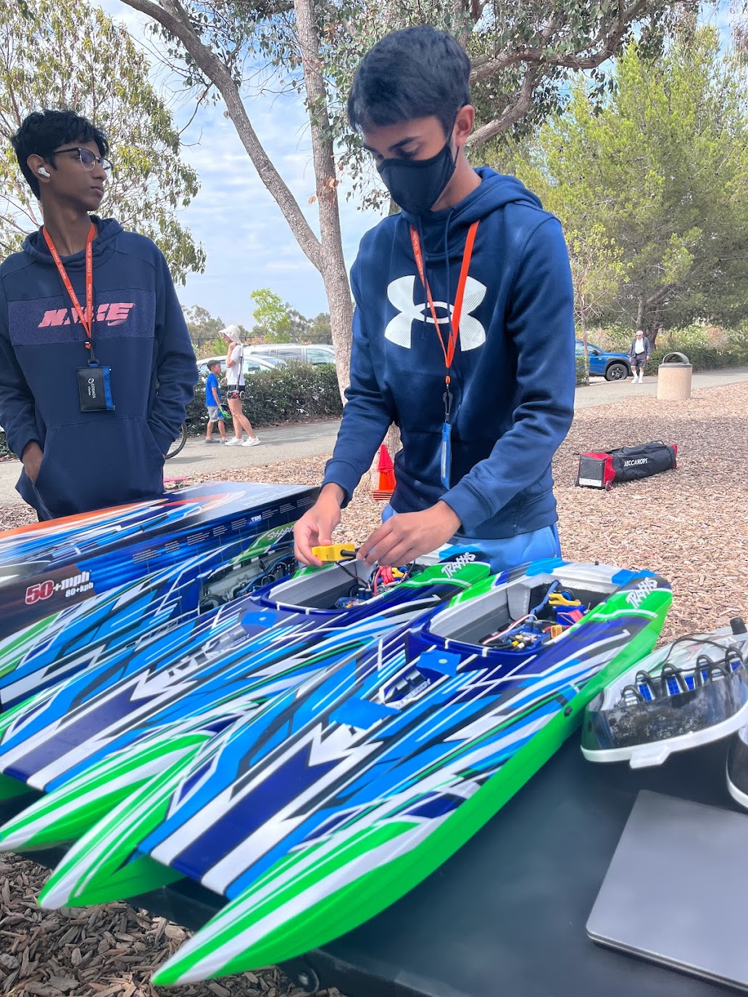
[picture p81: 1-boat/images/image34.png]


Daisy Zeng

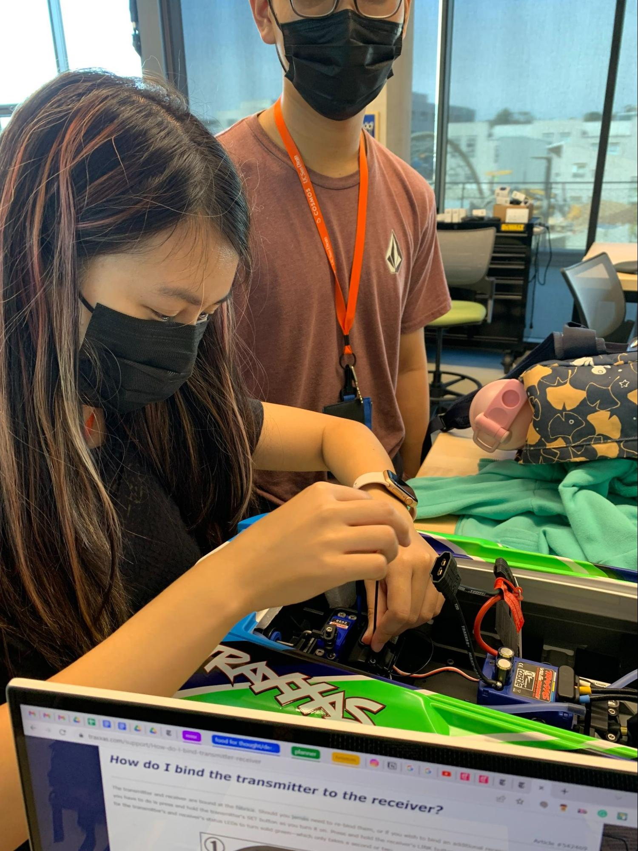
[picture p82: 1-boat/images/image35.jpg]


Deon Petrizzo

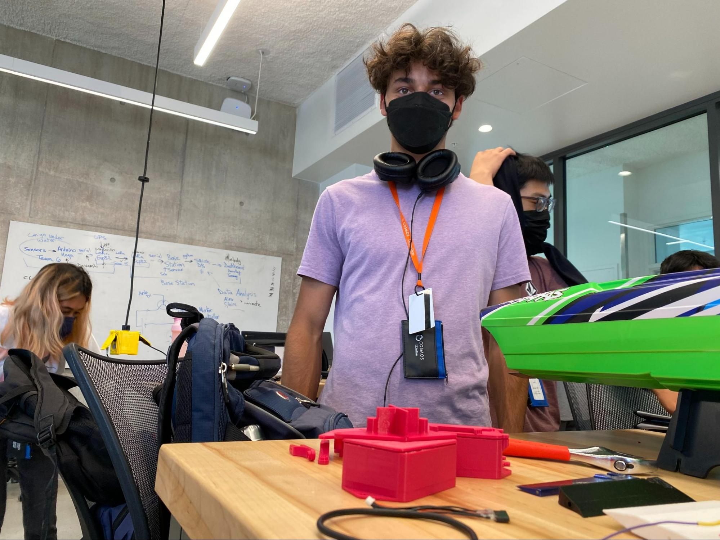
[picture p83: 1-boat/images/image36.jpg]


Tyler Synder

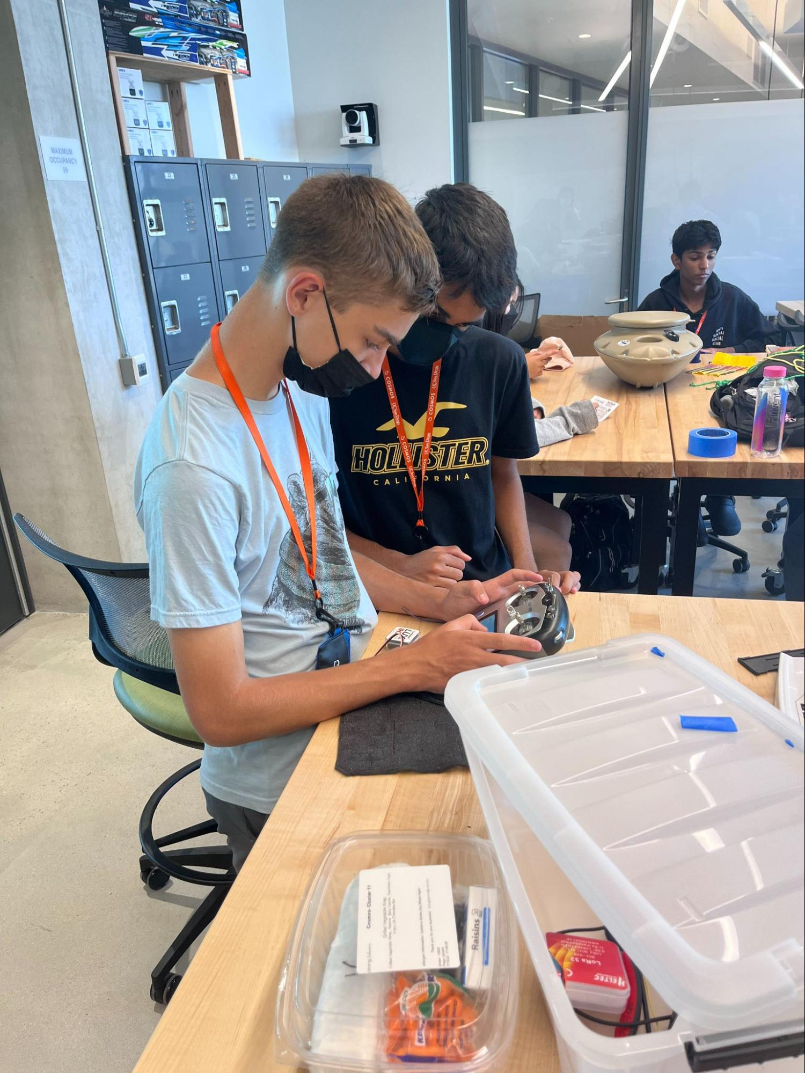
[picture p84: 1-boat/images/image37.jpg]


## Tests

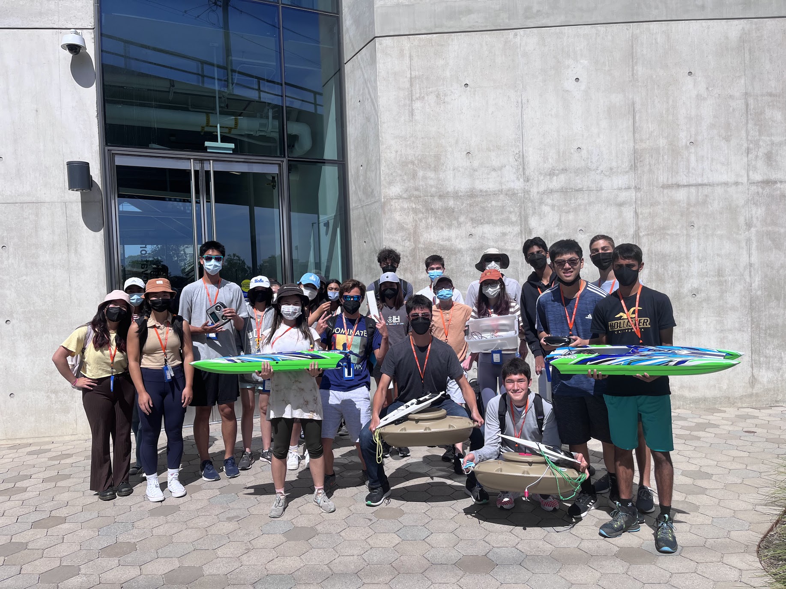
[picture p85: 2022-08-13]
1-boat/boat-team-images/first-test-day.jpg

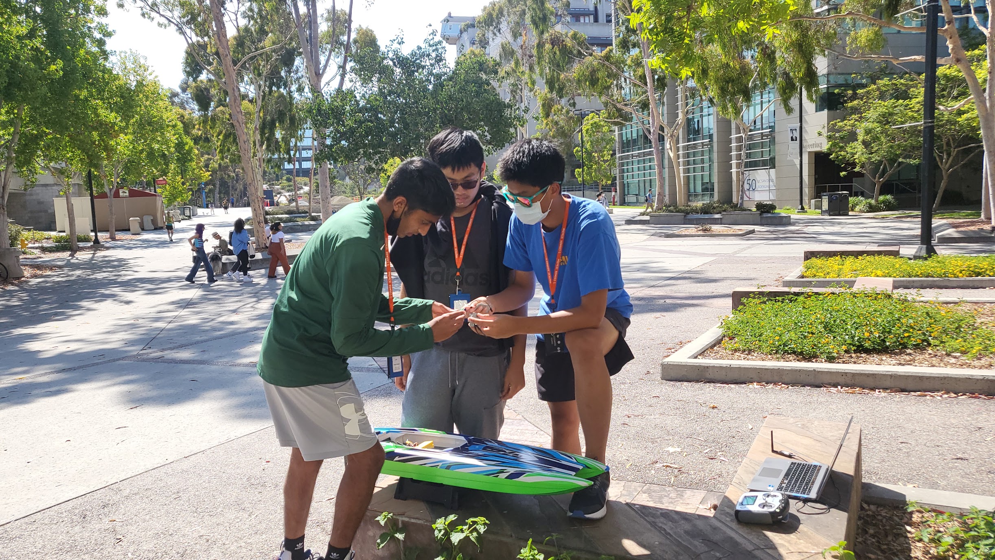
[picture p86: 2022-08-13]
1-boat/boat-team-images/first-pixhawk-test.jpg

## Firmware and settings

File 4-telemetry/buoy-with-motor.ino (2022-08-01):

///Motor Pins
#define outputA 13
#define outputB 12

//Encoder
#define encoder 0 
#define encoderRegLength 5 
int encoderRegister[encoderRegLength];  //  <----------------------Shift register
int encoderRegSum = 0;                  //  <-------------/
int encoderVal = 5;      //   <----------depth of buoy in rotations
int dir = 1;  //direction of motor  (positive means going into water)

#define stopper 22
#define stopperRegLength 10
int stopperRegister[stopperRegLength];  //  <----------------------Shift register
int stopperRegSum = 0;                  //  <-------------/
int stopperActive = 0;  //<----------will be 1 when buoy is at top

int state = 2;
int maxDepth = 5; //33
#define deploy 14

void t() {
  Serial.print("\t");
}

void up() {
  digitalWrite(outputA, HIGH);
  digitalWrite(outputB, LOW);
  Serial.println("UP_____________");
}

void down() {
  digitalWrite(outputB, HIGH);
  digitalWrite(outputA, LOW);
  Serial.println("DOWN_______________");
}

void stopMotor() {
  digitalWrite(outputA, LOW);
  digitalWrite(outputB, LOW);
  Serial.println("STOP_______________");

}


void setup() {
  // put your setup code here, to run once:
  Serial.begin(9600);
  Serial.print("Serial is now up");
  //motor
  pinMode(outputA, OUTPUT);
  pinMode(outputB, OUTPUT);

  pinMode(encoder, INPUT_PULLUP);
  pinMode(stopper, INPUT_PULLUP);

  pinMode(deploy, INPUT_PULLUP);

}

void loop() {
  //Telling the motors to stop


  //  // put your main code here, to run repeatedly:
  //  Serial.print(digitalRead(13));
  //  Serial.print('\t');
  //  Serial.print(digitalRead(encoderPin));
  //  Serial.print('\t');
  //  Serial.print(digitalRead(button));
  //  Serial.print('\t');
  //  Serial.println(digitalRead(button1));
  //  Serial.print('\t');
  //  Serial.println(digitalRead(12));
  //
  //


  //---------------------------------------------------------------------------------------------encoder shift register
  encoderRegSum = 0;
  for ( int index = 0; index < encoderRegLength - 1; index++) {
    encoderRegister[index] = encoderRegister[index + 1];
    encoderRegSum += encoderRegister[index];
  }
  encoderRegister[encoderRegLength - 1] = digitalRead(encoder);

  if ( encoderRegSum == 1  && encoderRegister[0] == HIGH) {  // falling edge (from high to low) (default is high ie. pullup)
    encoderVal += dir;
  }
  //-----------------------------------------------------------------------------------------------






  //---------------------------------------------------------------------------------------------stopper shift register
  stopperRegSum = 0;
  for ( int index = 0; index < stopperRegLength - 1; index++) {
    stopperRegister[index] = stopperRegister[index + 1];
    stopperRegSum += stopperRegister[index];
  }
  stopperRegister[stopperRegLength - 1] = digitalRead(stopper);

  if ( stopperRegSum < 3) {  // Magnet detected filter noise smaller than 9 cycles
    stopperActive = 1;
  }
  else {
    stopperActive = 0;
  }
  //-----------------------------------------------------------------------------------------------



  if (stopperActive == 1) encoderVal = 0;

  //wait for signal to go down
  if ( state == 0) {
    if (digitalRead(deploy) == LOW) {
      state = 1;
    }
    stopMotor();
  }

  //go down until reach bottom
  if (state == 1) {
    dir = 1; //depth larger ie. down
    if ( encoderVal >= maxDepth ) {
      state = 2;
    }
    down();
  }

  //go up until reach top
  if ( state  == 2 ) {
    dir = -1; //depth smaller ie. up
    if (encoderVal < 1) {
      state = 0;
    }
    up();
  }





  Serial.print(state); t();
  Serial.print(encoderVal); t();
  Serial.print(stopperActive); t();
  Serial.print(digitalRead(deploy)); t();
  //  Serial.print(stopperRegSum); t();
  //  Serial.print(stopperRegister[0]); t();
  //  Serial.print(digitalRead(stopper)); t();

  Serial.println();




}

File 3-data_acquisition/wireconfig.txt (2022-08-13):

Temperature sensor:
- GND -- GND
- DAT -- PIN 2
- VCC -- 5V

TDS sensor:
- - -- A0
- A - GND
- + -- 5V

pH sensor:
- V+ -- power/red
- G -- GND
- Po -- SIGNAL/A1

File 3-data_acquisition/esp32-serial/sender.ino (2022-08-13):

//tds sensor
/*
 Tds sensor to A0, 3.3V with esp32, 5V with Arduino Mega (either Voltage should be fine, refer to line 50 -gravityTds.setAref(3.3);- to change voltage), Gnd
 Ph sensor to A1, 5V, Gnd
 Temperature sensor to digital 2, 5V, Gnd
 */

#include <EEPROM.h>
#include "GravityTDS.h"

#include <SoftwareSerial.h>

SoftwareSerial portOne(4, 5); // RX, TX

int LEDpin = 13;
int number = 1;

//tds sensor pin
#define TdsSensorPin A0

//ph sensor pin
#define SensorPin A1          // the pH meter Analog output is connected with the Arduino's Analog


//temp stuff
// First we include the libraries
#include <OneWire.h> 
#include <DallasTemperature.h>
// Data wire is plugged into pin 2 on the Arduino 
#define ONE_WIRE_BUS 2
// Setup a oneWire instance to communicate with any OneWire devices  
// (not just Maxim/Dallas temperature ICs) 
OneWire oneWire(ONE_WIRE_BUS); 
// Pass our oneWire reference to Dallas Temperature. 
DallasTemperature sensors(&oneWire);



unsigned long int avgValue;  //Store the average value of the sensor feedback
float b;
int buf[10], temp;
float tdsValue = 0;
int tempValue;
String data;
GravityTDS gravityTds;

void setup()
{
    //for tds
    Serial.begin(9600);
    gravityTds.setPin(TdsSensorPin);
    gravityTds.setAref(3.3);  //reference voltage on ADC, default 5.0V on Arduino UNO
    gravityTds.setAdcRange(1024);  //1024 for 10bit ADC;4096 for 12bit ADC
    gravityTds.begin();  //initialization

    Serial.println("tds sensor begin");
    
    //for ph
    pinMode(13,OUTPUT);
    Serial.println("Ready");    //Test the serial monitor

    //for temp
    sensors.begin();
    while (!Serial);
    pinMode(13, OUTPUT);
    
}

void loop()
{
  //json format: data = "{'temp': " + String(temp) + ", 'ph': " + String(ph) + ", 'tds': " + String(tds) + "}";
  float temp=getTemp();
  float ph = getPh();
  float tds=getTds();
  // Serial.println(String(data[0]) + " " + String(data[1]) + " " + String(data[2]));
  /*digitalWrite(13, HIGH);       
  delay(1000);
  digitalWrite(13, LOW);*/
  Serial.println(String(temp) + "," + String(ph) + "," + String(tds) + "\n");
  delay(1000);

}

float getPh(){

    for(int i=0;i<10;i++)       //Get 10 sample value from the sensor for smooth the value
    { 
      buf[i]=analogRead(SensorPin);
      delay(10);
    }
  
  for(int i=0;i<9;i++)        //sort the analog from small to large
  {
    for(int j=i+1;j<10;j++)
    {
      if(buf[i]>buf[j])
      {
        temp=buf[i];
        buf[i]=buf[j];
        buf[j]=temp;
      }
    }
  }
  avgValue=0;
  for(int i=2;i<8;i++)                      //take the average value of 6 center sample
    avgValue+=buf[i];
  float phValue=(float)avgValue*5.0/1024/6; //convert the analog into millivolt
  phValue = 7-(phValue/57.14);                      //convert the millivolt into pH value 
  return phValue;
}

float getTemp(){
      // variables sent back: phValue, temperature, tdsValue
    sensors.requestTemperatures(); // Send the command to get temperature readings
    float temperature = sensors.getTempCByIndex(0); 
    return temperature;
}

float getTds(){
      //temperature = readTemperature();  //add your temperature sensor and read it
    gravityTds.setTemperature(getTemp());  // set the temperature and execute temperature compensation
    gravityTds.update();  //sample and calculate
    tdsValue = gravityTds.getTdsValue();  // then get the value, tds value is in ppm
    delay(1000);
    return tdsValue;
}

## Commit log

2022-08-03 Rename 2-buoy/Ph sensor.step to 2-buoy/Buoy1/Ph sensor.step
    [Ph sensor.step]
2022-08-03 Rename 2-buoy/TDS Sensor base.step to 2-buoy/Buoy1/TDS Sensor base.step
    [TDS Sensor base.step]
2022-08-03 Rename 2-buoy/Temperature holder.step to 2-buoy/Buoy1/Temperature holder.step
    [Temperature holder.step]
2022-08-03 Rename 2-buoy/TDS sensor enclosure.step to 2-buoy/Buoy1/TDS sensor enclosure.step
    [TDS sensor enclosure.step]
2022-08-03 Rename 2-buoy/Spool holder first iteration.step to 2-buoy/Buoy1/Spool holder first iteration.step
    [Spool holder first iteration.step]
2022-08-03 Rename 2-buoy/Spool wheel first iteration.step to 2-buoy/Buoy1/Spool wheel first iteration.step
    [Spool wheel first iteration.step]
2022-08-04 Rename 2-buoy/Buoy2/Motor_Casing_Structure (1).step to 2-buoy/Buoy2/PostTestDay/Motor_Casing_Structure (1).step
    [Motor_Casing_Structure (1).step]
2022-08-13 Update Data Acquisition
    [wireconfig.txt]
